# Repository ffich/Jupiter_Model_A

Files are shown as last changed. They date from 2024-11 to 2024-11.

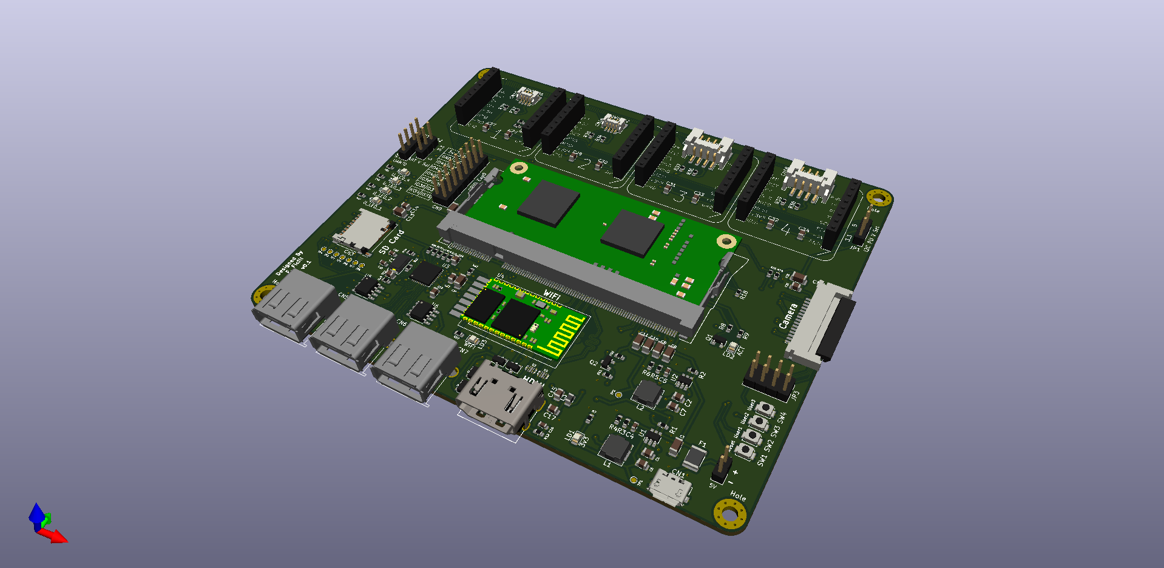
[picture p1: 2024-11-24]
10_HwProject/Jupiter_ModelA/50_3D/Jupiter_3D.png

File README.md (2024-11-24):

# Jupiter System
The Jupiter System is a system developed to leverage SW capabilities of Raspberry PI Compute Modules, by designing a system with an high level of HW configurability and scalability. This allows to use the power of the existing SW ecosystem in conjunction with a modular and scalable HW system, so that the user can take benefits from both of them. This HW configurability and expandability is given by adopting built-in sockets for some common peripheral add-on’s standard. The selected standards are the Mikroelektronika MikroBUS, the SeedStudio Grove and the Sparkfun QWIIC, which are widely used and open standards for HW expandability. The adherence to those standards allows the Jupiter System boards to be able to connect to the various expansion and breakout boards currently available on the market. These boards contain various types of sensor, actuators and interfaces, allowing for a very high level of HW scalability and modularity.

In this perspective the Jupiter System acts like a bridge between the Raspberry Pi SW and the HW world, allowing to take benefit from both the ecosystems.

Examples of application fields of Jupiter System are:
- Home automation System,
- IoT applications,
- Connectivity Applications,
- Monitoring and control Systems,
- Remote Control,
- Industrial Process control,
- Robotics applications,
- Test benches,
- Etc…

Concpet_Rpi

[youtube.com/watch?v=70Tqia20eaI](https://www.youtube.com/watch?v=70Tqia20eaI)

# Jupiter Model A
The Jupiter Model A is the desktop-version Jupiter board. It allows the user to experiment with the full potential of the Jupiter System. It's compatible with Raspberry CM3 and CM3+ (as the Raspberry Pi fundation does, we also strongly recommend to use CM3+ for newer design) and, among other peripherals, the board has 4 MikroBUS, 2 Grove and 2 Qwiic sockets that allow to create countless of combinations with Click, Grove or Qwiic slave devices.

Jupiter_3D

# MikroE Click Boards
There are more that 1000 click boards currently available on the market, and so many applications can be realized exploiting the power of raspberry (on SW side) and the high availability and modularity of the click boards (on the HW side).
For more information on click boards, please refer to the Mikroe website: https://www.mikroe.com/click





# Board Description
The HW block diagram of the Jupiter Model A is depicted below. As is possible to see, the brain of the system is a Raspberry PI compute module 3 or 3+, connected to a broad list of peripherals. 



More in details, the board is populated with:
-	3x USB
-	1x WiFi
-	1x CSI Interface
-	1x DSI interface
-	1x Boot SD card Socket
-	1x Serial Port
-	Up to 16 GPIO
-	4x User LEDs
-	2x User Buttons

Additionally the board contains 4 MikroBUS Sockets that allow to interface with MikroBUS compatible devices, like the click boards, 2 Groove and 2 QWIIC connectors.

HW Details

# Examples of combination with Click Boards

Model_A_1

Model_A_2

Model_A_3

Model_A_4

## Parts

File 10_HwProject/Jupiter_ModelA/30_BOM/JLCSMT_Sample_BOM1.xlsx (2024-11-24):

Comment | Designator | Footprint | LCSC Part #（optional）
100uF | C1 | CASE-B_3528 | C16133
100nF | C2, C9, C10 | 0603_C | C14663
10uF | C3-5 | 1206_C | C13585
15KΩ | R5, R6 | 0603_R | C22809

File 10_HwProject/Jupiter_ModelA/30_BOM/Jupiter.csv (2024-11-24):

Reference | Quantity | Value | Footprint | Description | Manf#
C1 C6 C2 C7 C15 | 5 | 22uF | Capacitor_SMD:C_0805_2012Metric | 0805_C
C12 C13 | 2 | 4.7uF | Capacitor_SMD:C_1206_3216Metric | 1206_C
C14 C22 C21 C23 C26 C27 C29 C31 C33 C28 C30 C32 C34 | 13 | 100nF | Capacitor_SMD:C_0805_2012Metric | 0805_C
C16 | 1 | 1nF | Capacitor_SMD:C_0603_1608Metric | 0603_C
C17 | 1 | 1nF | Capacitor_SMD:C_0805_2012Metric | 0805_C
C19 | 1 | 100n | Capacitor_SMD:C_0805_2012Metric | 0805_C
C20 C18 | 2 | 18pF | Capacitor_SMD:C_0603_1608Metric | 0603_C
C24 | 1 | 100uF | Capacitor_SMD:C_1206_3216Metric | 1206_C
C25 | 1 | 10uF | Capacitor_SMD:C_1206_3216Metric | 1206_C
C3 C8 C9 C10 C11 | 5 | 47uF | Capacitor_SMD:C_1206_3216Metric | 1206_C
C5 C4 | 2 | 22pF | Capacitor_SMD:C_0603_1608Metric | 0603_C
CN1 | 1 | USB_B_Micro | Connector_USB:USB_Micro-B_Molex_47346-0001 | USB MicroB Connector | Molex_47346
CN10 | 1 | 1 | mikroBUS:MIKROBUS_HOST_CONN | Mikrobus Socket - 2x PinHeader_2.54mm 1x08 female
CN11 | 1 | 2 | mikroBUS:MIKROBUS_HOST_CONN | Mikrobus Socket - 2x PinHeader_2.54mm 1x08 female
CN12 | 1 | UART0 | Connector_PinHeader_2.54mm:PinHeader_1x04_P2.54mm_Vertical | PinHeader_2.54mm 1x04 male
CN13 | 1 | 3 | mikroBUS:MIKROBUS_HOST_CONN | Mikrobus Socket - 2x PinHeader_2.54mm 1x08 female
CN14 | 1 | 4 | mikroBUS:MIKROBUS_HOST_CONN | Mikrobus Socket - 2x PinHeader_2.54mm 1x08 female
CN15 | 1 | QWIIC#1 | Connector_JST:JST_SH_SM04B-SRSS-TB_1x04-1MP_P1.00mm_Horizontal | JST_SH_SM04B-SRSS-TB_1x04-1MP_P1.00mm_Horizontal
CN16 | 1 | QWIIC#2 | Connector_JST:JST_SH_SM04B-SRSS-TB_1x04-1MP_P1.00mm_Horizontal | JST_SH_SM04B-SRSS-TB_1x04-1MP_P1.00mm_Horizontal
CN17 | 1 | GROVE#1 | Connector_JST:JST_PH_S4B-PH-SM4-TB_1x04-1MP_P2.00mm_Horizontal | JST_PH_S4B-PH-SM4-TB_1x04-1MP_P2.00mm_Horizontal
CN18 | 1 | GROVE#2 | Connector_JST:JST_PH_S4B-PH-SM4-TB_1x04-1MP_P2.00mm_Horizontal | JST_PH_S4B-PH-SM4-TB_1x04-1MP_P2.00mm_Horizontal
CN2 | 1 | 5V | Connector_PinHeader_2.54mm:PinHeader_1x02_P2.54mm_Vertical | PinHeader_1x02_P2.54mm_Vertical
CN3 | 1 | MicroSD | Connector_Card:microSD_HC_Hirose_DM3D-SF | MicroSD Connector | Hirose_DM3D-SF
CN4 | 1 | HDMI | FF_Connectors:HDMI_TypeA | HDMI Type A Connector
CN5 | 1 | USB_H2 | Connector_USB:USB_A_Stewart_SS-52100-001_Horizontal | USB Type A Connector | Stewart_SS-52100-001_Horizontal
CN6 | 1 | USB_H3 | Connector_USB:USB_A_Stewart_SS-52100-001_Horizontal | USB Type A Connector | Stewart_SS-52100-001_Horizontal
CN7 | 1 | USB_H4 | Connector_USB:USB_A_Stewart_SS-52100-001_Horizontal | USB Type A Connector | Stewart_SS-52100-001_Horizontal
CN8 | 1 | FPC15 | Connector_FFC-FPC:TE_1-84952-5_1x15-1MP_P1.0mm_Horizontal | FPC 15 Connector | TE_1-84952-5_1x15-1MP_P1.0mm_Horizontal
CN9 | 1 | GPIO Exp0 | Connector_PinHeader_2.54mm:PinHeader_2x08_P2.54mm_Vertical | PinHeader_2.54mm 2x08 male
D1 D2 D4 D6 | 4 | BAV99 | Package_TO_SOT_SMD:SOT-23 | SOT-23
D3 D5 | 2 | RCLAMP0524P | FF_Diodes:RCLAMP0524P | SLP2510P8-8
F1 | 1 | MSMF200 | Fuse:Fuse_1812_4532Metric | SMD 1812
JP1 | 1 | I2C PU V Sel | Connector_PinHeader_2.54mm:PinHeader_1x03_P2.54mm_Vertical | PinHeader_1x03 male
JP2 | 1 | UART V Sel | Connector_PinHeader_2.54mm:PinHeader_1x03_P2.54mm_Vertical | PinHeader_1x03 male
JP3 | 1 | Cam Jpr | Connector_PinHeader_2.54mm:PinHeader_2x04_P2.54mm_Vertical | PinHeader_2x04 male
L1 L2 | 2 | 2.2uH 3A | Inductor_SMD:L_Sunlord_MWSA0518_5.4x5.2mm | L_Sunlord_MWSA0518_5.4x5.2mm
L3 | 1 | Bead | Inductor_SMD:L_0805_2012Metric | 0805_L
LD1 | 1 | 3v3 | LED_SMD:LED_0805_2012Metric | LED_0805
LD2 | 1 | ACT | LED_SMD:LED_0805_2012Metric | LED_0805
LD3 | 1 | WiFi | LED_SMD:LED_0805_2012Metric | LED_0805
LD4 | 1 | U_LED_1 | LED_SMD:LED_0805_2012Metric | LED_0805
LD5 | 1 | U_LED_2 | LED_SMD:LED_0805_2012Metric | LED_0805
LD6 | 1 | U_LED_3 | LED_SMD:LED_0805_2012Metric | LED_0805
LD7 | 1 | U_LED_4 | LED_SMD:LED_0805_2012Metric | LED_0805
MD1 | 1 | RPi Compute Module | RPi_CM:Conn_TE-DDR2-SODIMM-0.6-200P-doublesided | SODIMM 200 | TE-DDR2-SODIMM-0.6-200P-doublesided
Q1 Q2 | 2 | S8050 | Package_TO_SOT_SMD:SOT-23 | S8050 SOT-23
R1 R2 R8 | 3 | 100k | Resistor_SMD:R_0603_1608Metric | 0603_R
R11 R10 R21 R17 R20 R16 R15 R14 | 8 | 10k | Resistor_SMD:R_0603_1608Metric | 0603_R
R12 | 1 | 100 | Resistor_SMD:R_0603_1608Metric | 0603_R
R13 | 1 | 1M | Resistor_SMD:R_0603_1608Metric | 0603_R
R18 | 1 | 1k | Resistor_SMD:R_0603_1608Metric | 0603_R
R19 | 1 | 12k | Resistor_SMD:R_0603_1608Metric | 0603_R
R23 | 1 | 4.7k | Resistor_SMD:R_0603_1608Metric | 0603_R
R24 R25 R27 R26 R33 R32 R35 R34 R37 R36 R39 R38 | 12 | 2.2k | Resistor_SMD:R_0603_1608Metric | 0603_R
R3 R6 | 2 | 150k | Resistor_SMD:R_0603_1608Metric | 0603_R
R4 | 1 | 33k | Resistor_SMD:R_0603_1608Metric | 0603_R
R5 | 1 | 300k | Resistor_SMD:R_0603_1608Metric | 0603_R
R7 R28 R29 R30 R31 | 5 | 220 | Resistor_SMD:R_0603_1608Metric | 0603_R
R9 R22 | 2 | 330 | Resistor_SMD:R_0603_1608Metric | 0603_R
SW1 | 1 | Reset | Button_Switch_SMD:SW_SPST_B3U-1000P | Omron B3U-1000P
SW2 | 1 | User1 | Button_Switch_SMD:SW_SPST_B3U-1000P | Omron B3U-1000P
SW3 | 1 | User2 | Button_Switch_SMD:SW_SPST_B3U-1000P | Omron B3U-1000P
SW4 | 1 | User3 | Button_Switch_SMD:SW_SPST_B3U-1000P | Omron B3U-1000P
TP1 TP2 TP5 TP9 TP8 TP7 TP6 TP4 TP3 | 9 |  | TestPoint:TestPoint_Pad_D1.0mm
U1 U2 | 2 | AP3402 | Package_TO_SOT_SMD:TSOT-23-6 | TSOT-23-6
U3 | 1 | USB2514B_Bi | Package_DFN_QFN:QFN-36-1EP_6x6mm_P0.5mm_EP3.7x3.7mm | QFN-36
U4 | 1 | GWF_3M08 | FF_Modules:GWF_3M08_WifiModule | Kit Wifi GWF-3M08
U5 U6 | 2 | MIC2026-1BM | Package_SO:SOIC-8_3.9x4.9mm_P1.27mm | SOIC-8
Y1 | 1 | 24 MHz | Crystal:Crystal_SMD_5032-2Pin_5.0x3.2mm | SMD_5032

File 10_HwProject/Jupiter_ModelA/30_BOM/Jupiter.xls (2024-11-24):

Comment | Designator | Footprint
22uF | C1 C6 C2 C7 C35 | 0805_C
4.7uF | C12 C13 | 1206_C
100nF | C14 C20 C19 C21 C26 C25 C27 C29 C31 C33 C28 C30 C32 C34 | 0805_C
1nF | C15 | 0603_C
100n | C17 | 0805_C
18pF | C18 C16 | 0603_C
100uF | C22 | 1206_C
10uF | C24 C23 | 1206_C
47uF | C3 C8 C9 C10 C11 | 1206_C
1nF | C36 | 0805_C
22pF | C5 C4 | 0603_C
USB_B_Micro | CN1 | USB MicroB Connector
GPIO Exp1 | CN10 | PinHeader_2.54mm 2x08 male
UART0 | CN11 | PinHeader_2.54mm 1x04 male
1 | CN12 | Mikrobus Socket - 2x PinHeader_2.54mm 1x08 female
2 | CN13 | Mikrobus Socket - 2x PinHeader_2.54mm 1x08 female
3 | CN14 | Mikrobus Socket - 2x PinHeader_2.54mm 1x08 female
4 | CN15 | Mikrobus Socket - 2x PinHeader_2.54mm 1x08 female
Pwr | CN16
5V | CN17
MicroSD | CN2 | MicroSD Connector
HDMI | CN3 | HDMI Type A Connector
USB_H2 | CN4 | USB Type A Connector
USB_H3 | CN5 | USB Type A Connector
USB_H4 | CN6 | USB Type A Connector
FPC15 | CN8 CN7 | FPC 15 Connector
GPIO Exp0 | CN9 | PinHeader_2.54mm 2x08 male
BAV99 | D1 D2 D4 D6 | SOT-23
RCLAMP0524P | D3 D5 | SLP2510P8-8
MSMF200 | F1 | SMD 1812
Fuse Bp | JP1 | PinHeader_1x02 male
I2C PU V Sel | JP2 | PinHeader_1x03 male
UART V Sel | JP3 | PinHeader_1x03 male
2.2uH 3A | L1 L2 | L_Sunlord_MWSA0518_5.4x5.2mm
Bead | L3 | 0805_L
5v | LD1 | LED_0805
3v3 | LD2 | LED_0805
1V8 | LD3 | LED_0805
ACT | LD4 | LED_0805
WiFi | LD5 | LED_0805
U_LED_1 | LD6 | LED_0805
U_LED_2 | LD7 | LED_0805
U_LED_3 | LD8 | LED_0805
U_LED_4 | LD9 | LED_0805
RPi Compute Module | MD1 | SODIMM 200
S8050 | Q1 Q2 | S8050 SOT-23
100k | R1 R2 R10 | 0603_R
330 | R11 R24 | 0603_R
10k | R13 R12 R23 R19 R22 R18 R17 R16 | 0603_R
100 | R14 | 0603_R
1M | R15 | 0603_R
1k | R20 | 0603_R
12k | R21 | 0603_R
4.7k | R25 | 0603_R
2.2k | R26 R27 R29 R28 | 0603_R
150k | R3 R6 | 0603_R
33k | R4 | 0603_R
300k | R5 | 0603_R
220 | R7 R8 R9 R30 R31 R32 R33 | 0603_R
 | TP1 TP2 TP6 TP7 TP11 TP15 TP14 TP13 TP12 TP10 TP9
AP3402 | U1 U2 | TSOT-23-6
USB2514B_Bi | U3 | QFN-36
GWF_3M08 | U4
MIC2026-1BM | U5 U6 | SOIC-8
24 MHz | Y1 | SMD_5032

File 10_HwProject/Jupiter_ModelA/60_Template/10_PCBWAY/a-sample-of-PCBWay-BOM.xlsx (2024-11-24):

 |  |  | xxxx xxxx xxxxx xxPCS BOM (Sample Bill of Materials)
Item # | *Designator | *Qty | Manufacturer | *Mfg Part # | Description / Value | *Package/Footprint | Type | Your Instructions / Notes
1 | U1 | 1 | Linear | LTC3780EG#PBF | IC BUCK-BOOST CONV 24-SSOP | 24-SSOP | SMD
2 | U2,U4 | 2 | Fairchild | LM2904M | IC OPAMP DUAL -40-85 C 8-SOIC | 8-SOIC | DNS
3 | U3 | 1 | ON | LM317MBDTG | LM317M IC REG VOLT ADJ 500MA DPAK | DPAK | SMD
4 | U5 | 1 | Microchip | PIC16F690-I/SS | IC PIC MCU FLASH 4KX14 20SSOP | 20SSOP | SMD
5 | Q1 | 1 | Diodes Inc | GBJ10005-F | RECT BRIDGE GPP 50V 10A GBJ | GBJ | SMD
6 | R14,R18 | 2 | Panasonic | ERJ-6ENF4701V | RES 4.70K OHM 1/8W 1% 0805 SMD | 0805 | SMD
7 | R15 | 1 | Susumu | RL3720WT-R022-F | RES .022 OHM 1W 1% 0815 SMD | 0815 | SMD
8 | R16, R31 | 2 | Panasonic | ERJ-6ENF4702V | RES 47.0K OHM 1/8W 1% 0805 SMD | 0805 | SMD
9 | C5 | 1 | Murata | GRM21BR71C225KA12L | CAP CER 2.2UF 16V X7R 0805 | 0805 | SMD
10 | C7 | 1 | Murata | GRM21BR71C475KA73L | CAP CER 4.7UF 16V X7R 0805 | 0805 | DNS
11 | C8,C22 | 2 | Muruta | GRM21BR71C105KA01L | CAP CER 1.0UF 16V 10% X7R 0805 | 0805 | SMD
12 | CN6 | 1 | Molex | 538-53398-0671 | 1.25mm Connectors VERTICAL HDR SMT 6P | SMT 6P | SMD
13 | L1,L2 | 2 | Coiltronics | DR127-150-R | INDUCTOR SHIELD PWR 15UH SMD | SMD | SMD
14 | L3 | 1 | TDK | ACM1211-102-2PL-TL | CHOKE COMM MODE 1000 OHM 6A SM | SMD | SMD
15 | CN3,CN4 | 2 | Molex | 53047-0510 | CONN HEADER 5POS 1.25MM VERT TIN | 5POS | thru-hole
Need a quick and accurante quote? Need an efficient production? Please read SMT Ordering Necessary Files & Info in 1 minute. Thank you very much! (https://www.pcbway.com/smt_ordering_guide.html)
Click for Instructions on How to Create a BOM (https://www.pcbway.com/blog/PCB_Assembly/How_to_Build_a_BOM__Bill_Of_Materials_.html)

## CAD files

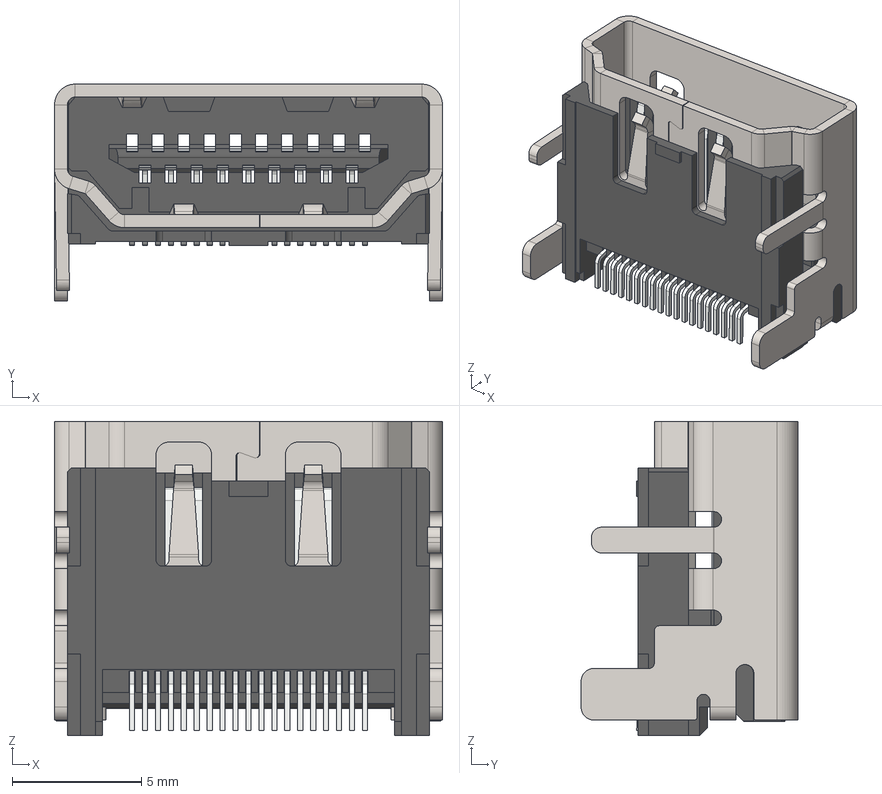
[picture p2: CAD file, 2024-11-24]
10_HwProject/Jupiter_ModelA/10_PCB/Jupiter/3d/molex_0471510001.STEP
15.0 x 8.38 x 12.1 mm

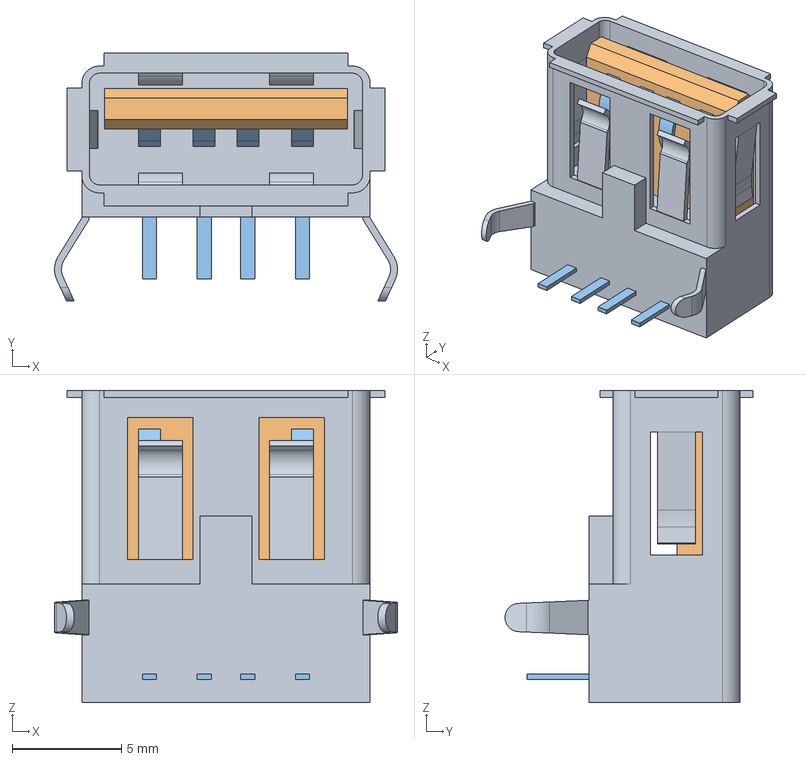
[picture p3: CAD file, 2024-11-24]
10_HwProject/Jupiter_ModelA/10_PCB/Jupiter/3d/USBR-A-S-F-O-TH.stp
15.7 x 11.3 x 14.3 mm
_USBR-A-S-TH_s
_USBR-A-S-TH_b
_USBR-A-S-TH_p

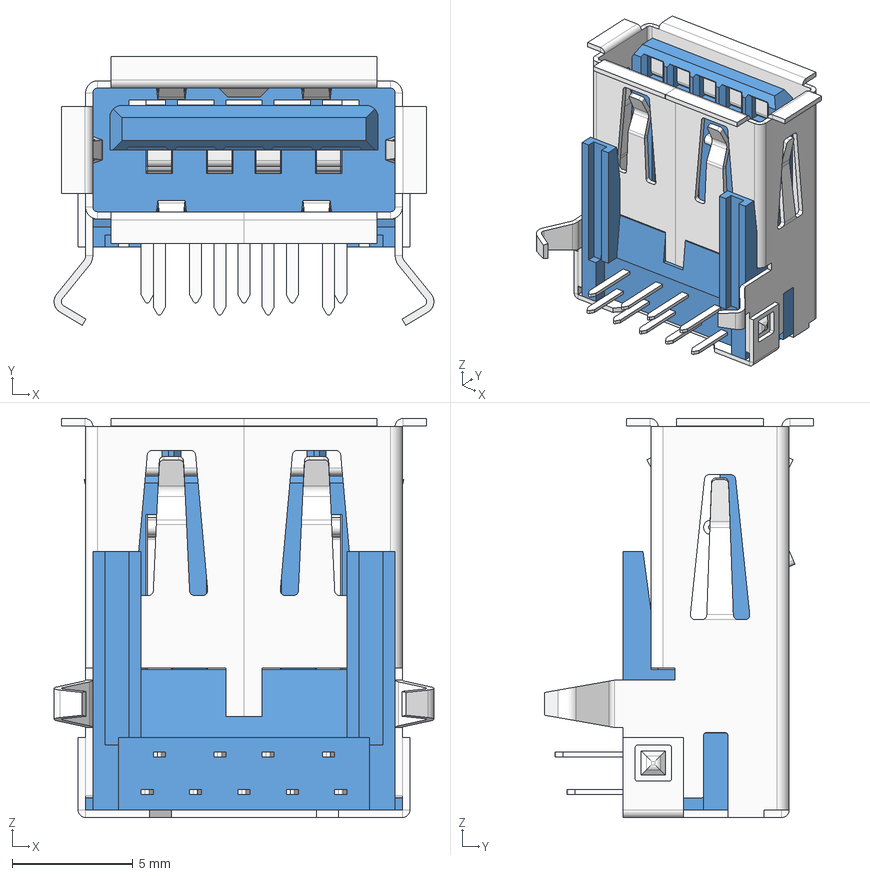
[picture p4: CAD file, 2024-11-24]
10_HwProject/Jupiter_ModelA/10_PCB/Jupiter/3d/USB 3.0 A Recepticle.stp
15.7 x 11.1 x 16.5 mm
USB 3.0 A Recepticle Shell
USB 3.0 A Recepticle Insert Fit
USB 3.0 A Recepticle Rear Insert Fit
USB 3.0 A Recepticle Lower Pin x 4
USB 3.0 A Recepticle Upper Pin x 5

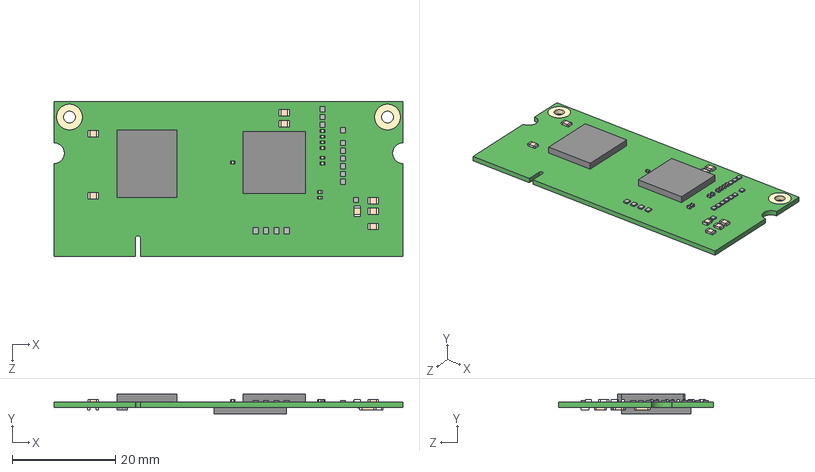
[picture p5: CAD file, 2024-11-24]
10_HwProject/Jupiter_ModelA/10_PCB/Jupiter/3d/RASPBERRYPI-CM3.STEP
67.6 x 3.80 x 30.0 mm

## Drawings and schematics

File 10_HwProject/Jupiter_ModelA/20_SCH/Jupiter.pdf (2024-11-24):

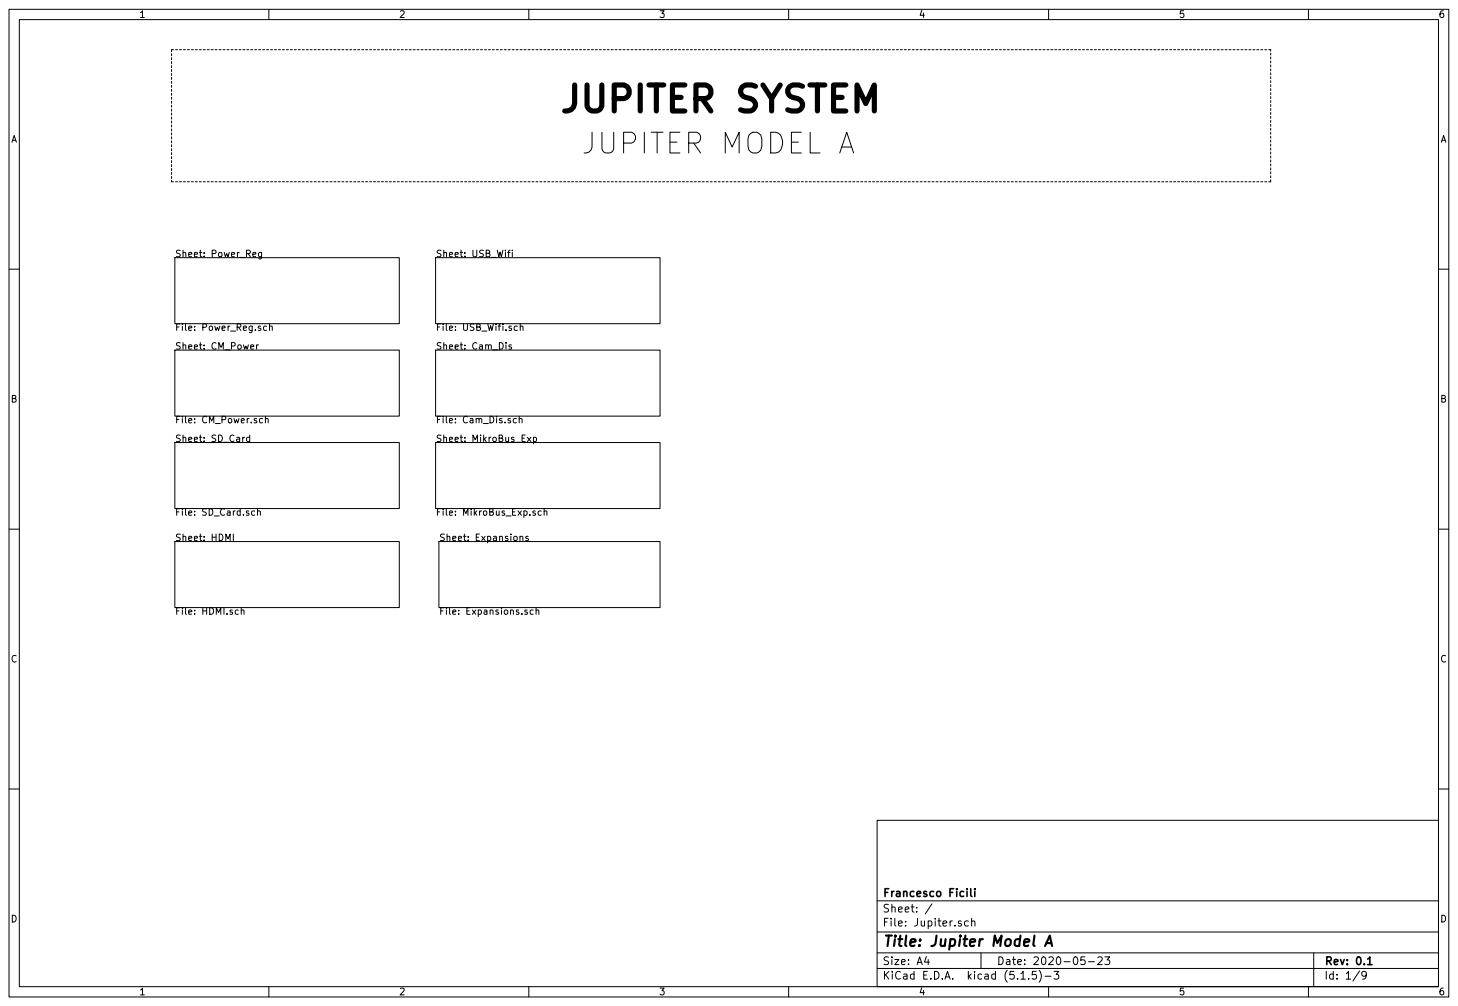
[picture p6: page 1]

File: Jupiter.sch Sheet: / Francesco Ficili

Id: 1/9 Title: Jupiter Model A

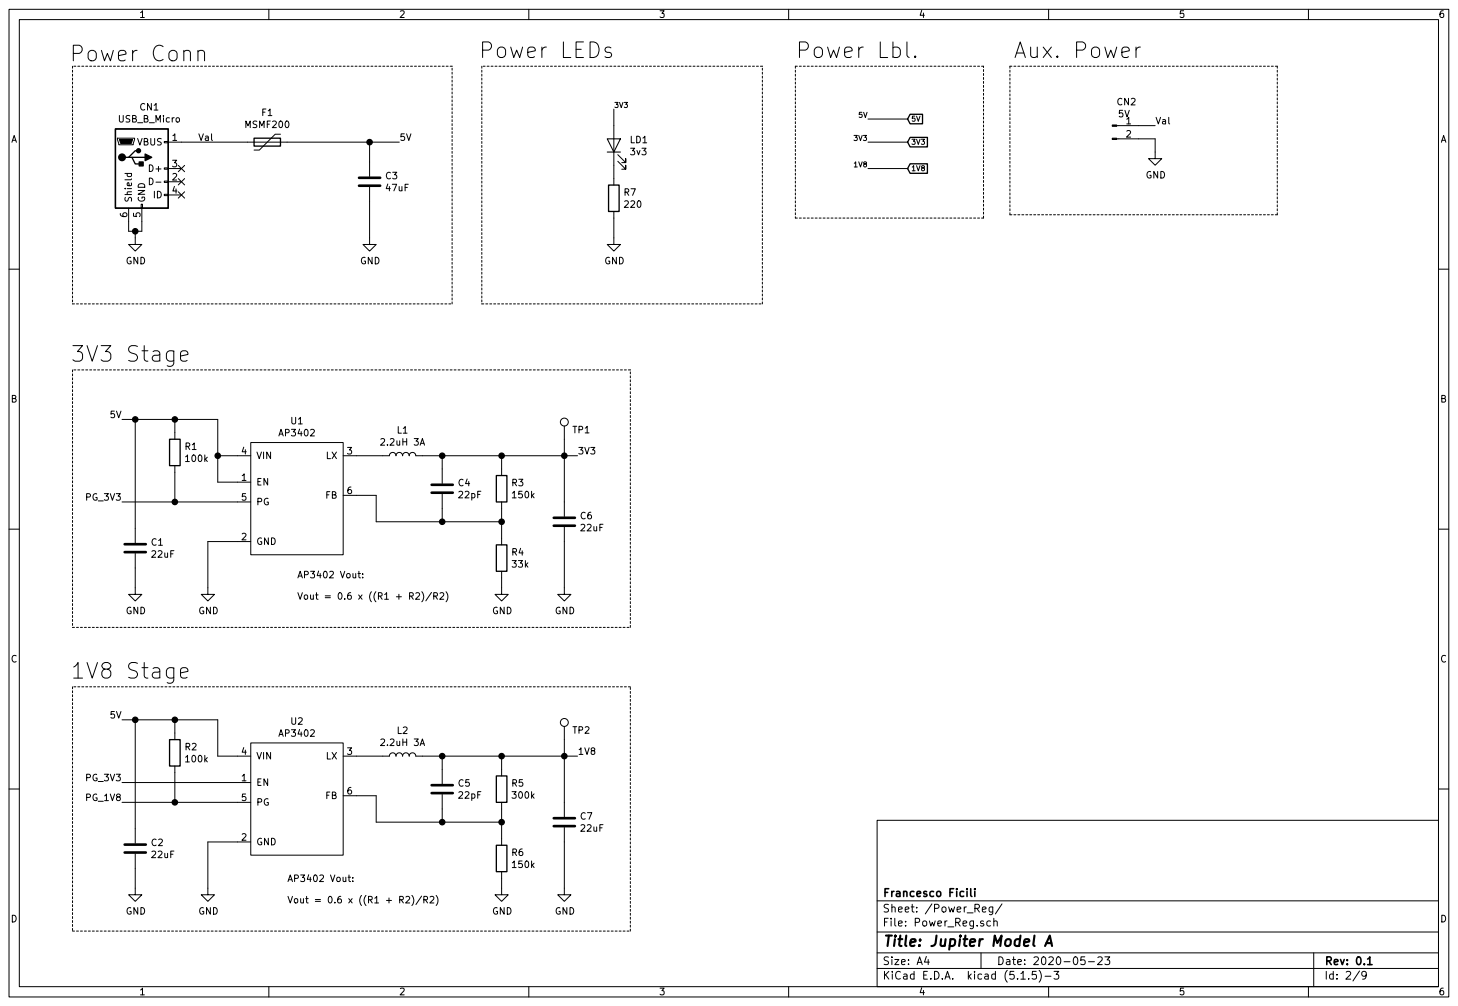
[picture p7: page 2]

3V3 Stage
AP3402 Vout: Vout = 0.6 x ((R1 + R2)/R2)

File: Power_Reg.sch
Id: 2/9 Title: Jupiter Model A

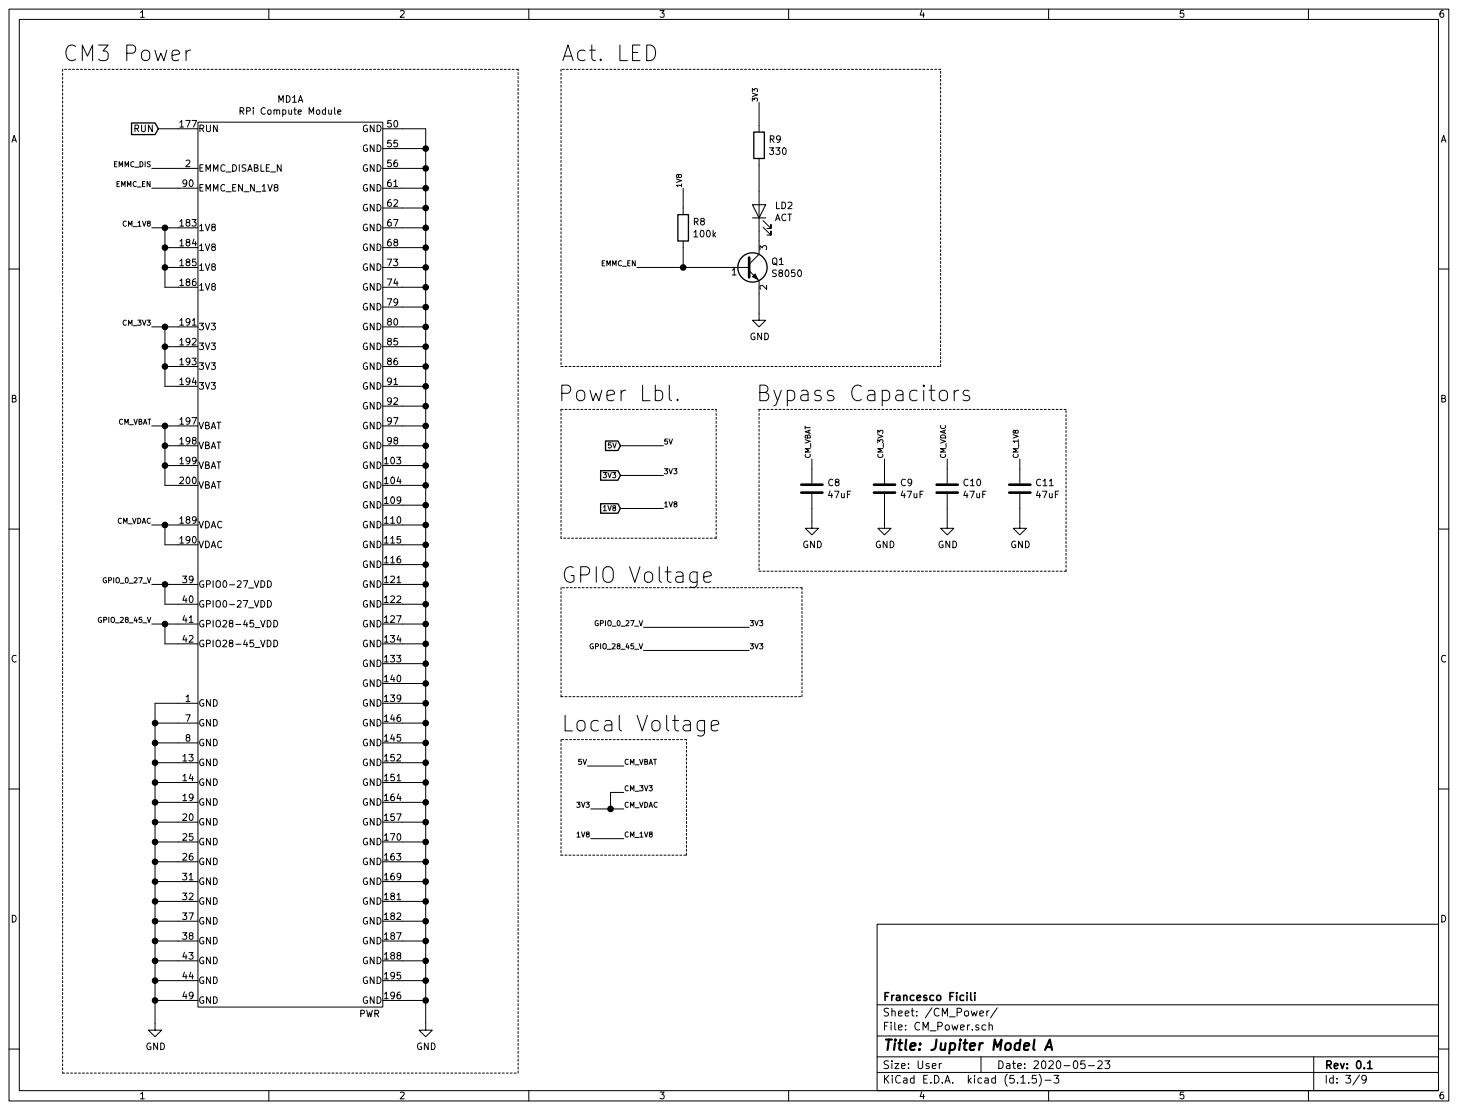
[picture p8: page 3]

File: CM_Power.sch
Id: 3/9 Title: Jupiter Model A

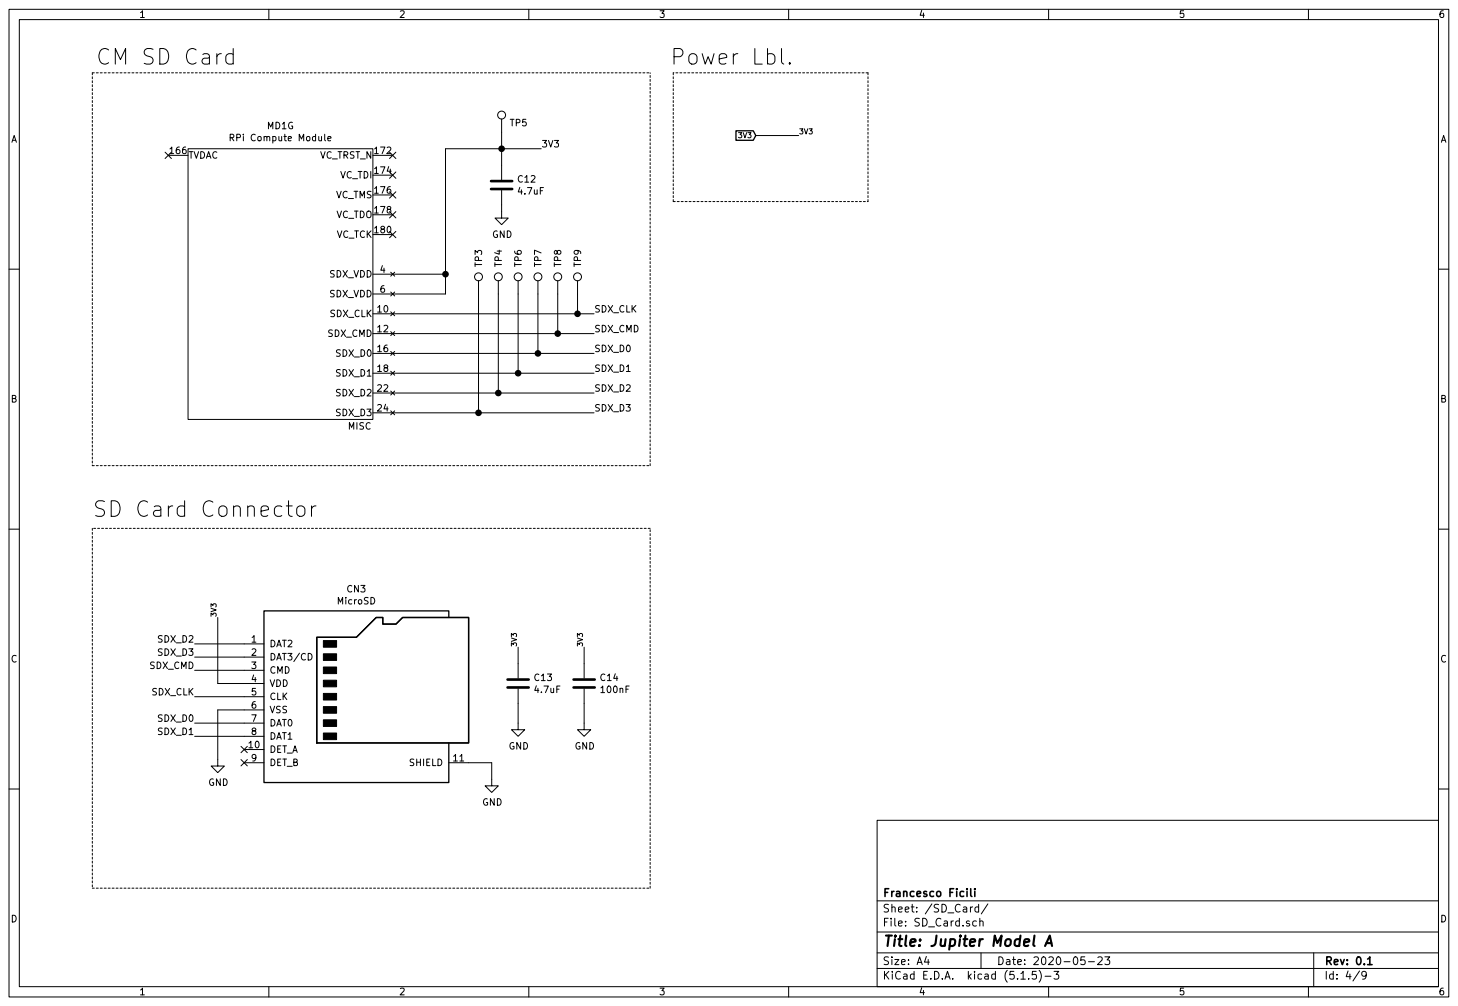
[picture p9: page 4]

File: SD_Card.sch
Id: 4/9 Title: Jupiter Model A

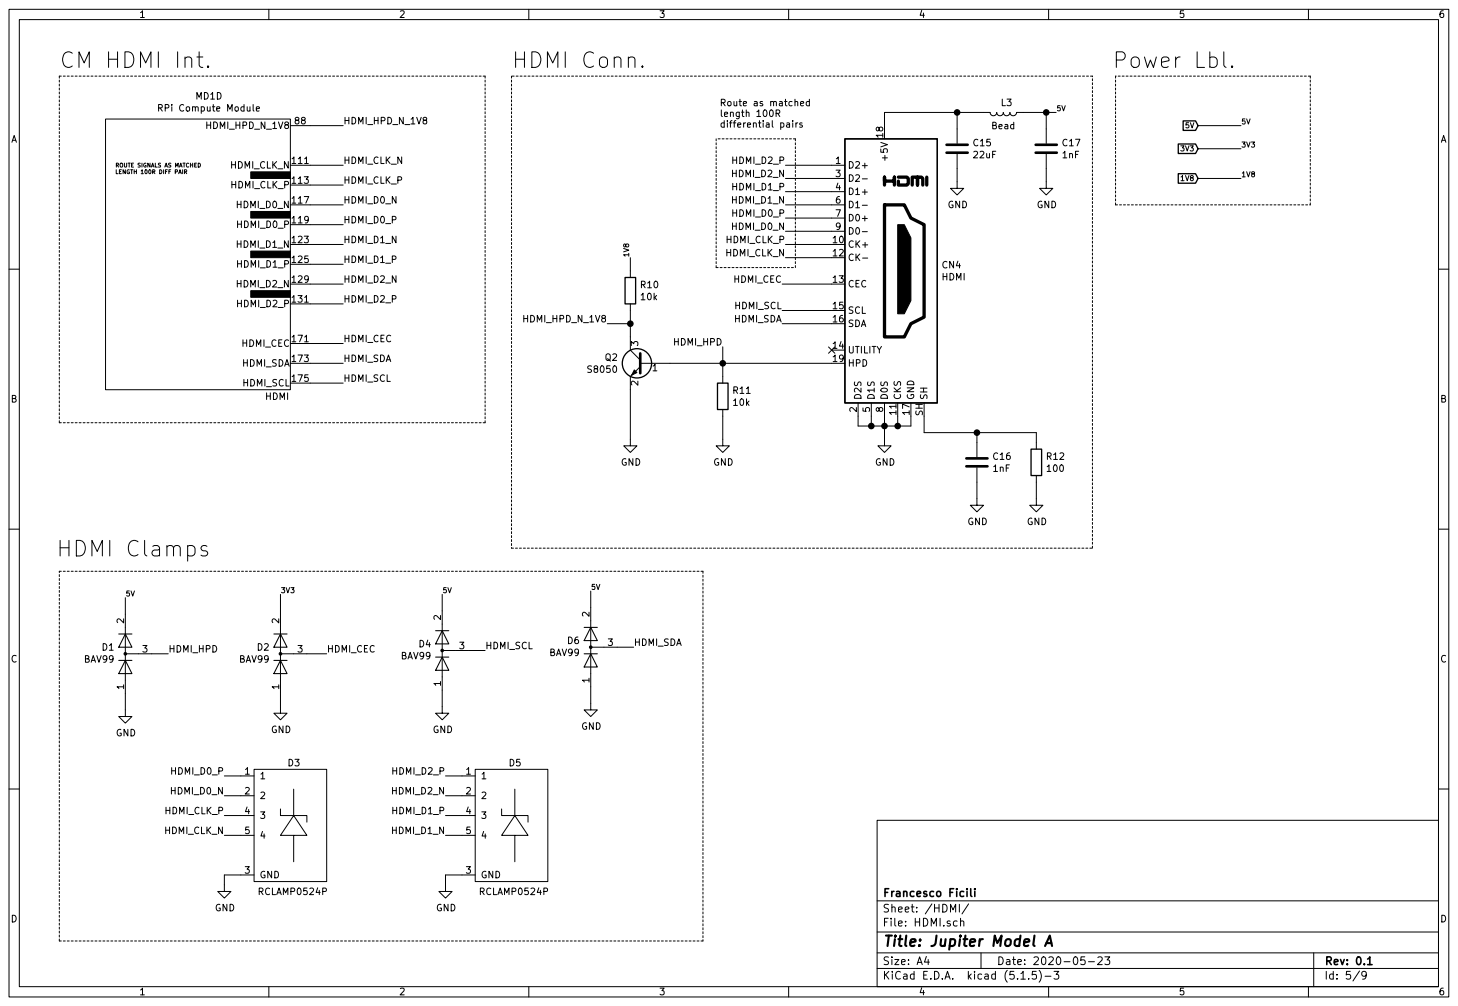
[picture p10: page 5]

Id: 5/9 Title: Jupiter Model A

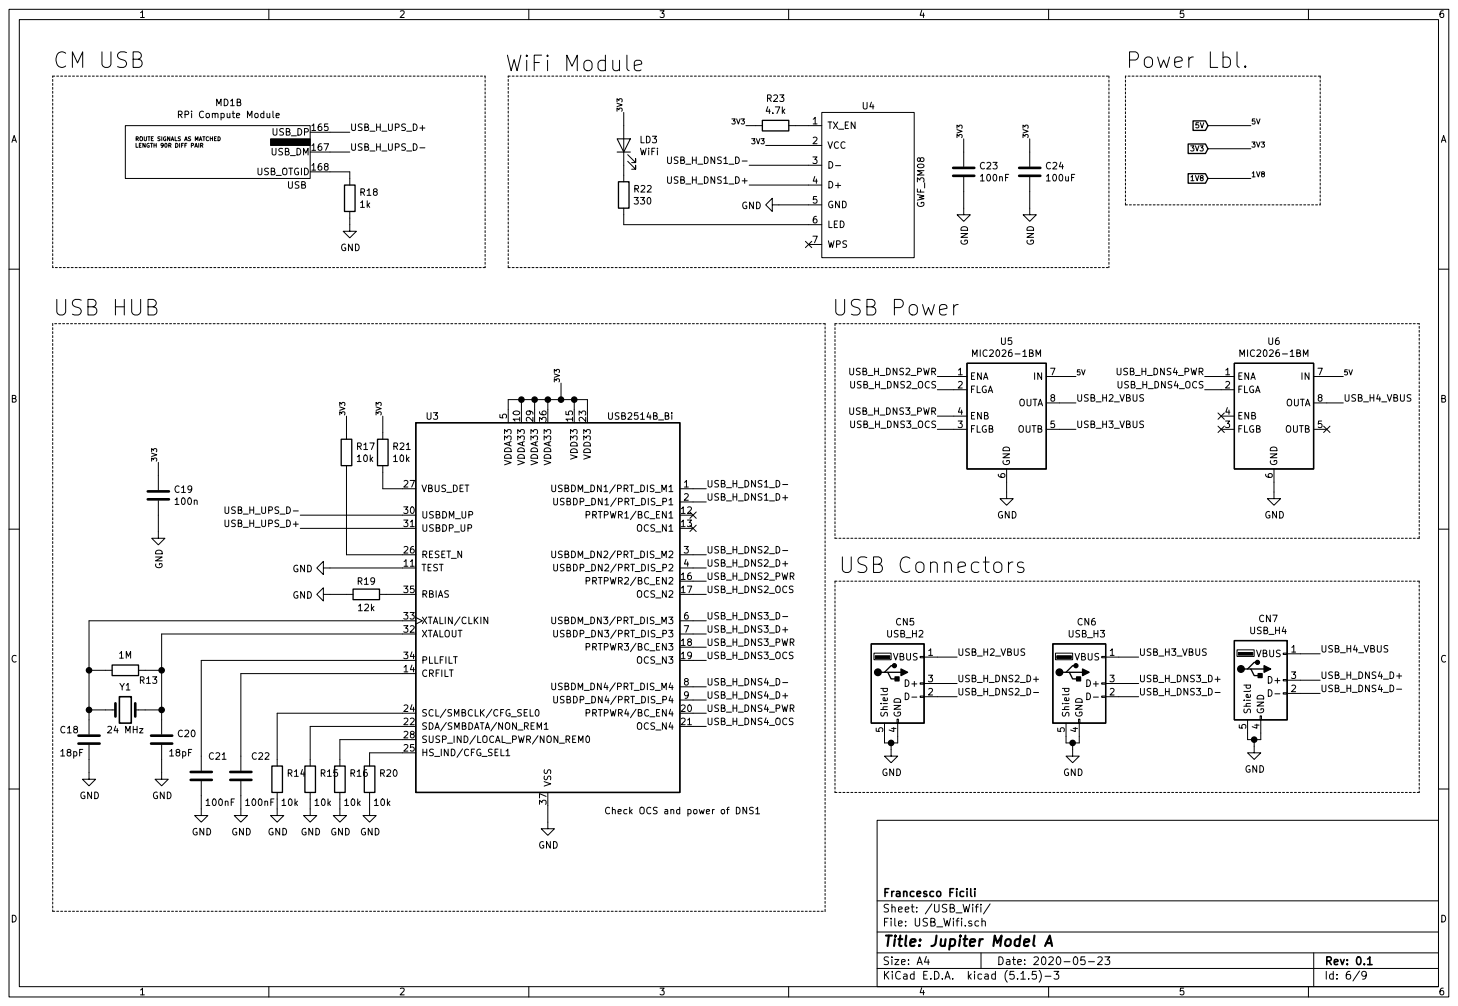
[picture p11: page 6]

5 CN6 USB_H3 GND GND GND GND GND

Check OCS and power of DNS1

File: USB_Wifi.sch
Id: 6/9 Title: Jupiter Model A

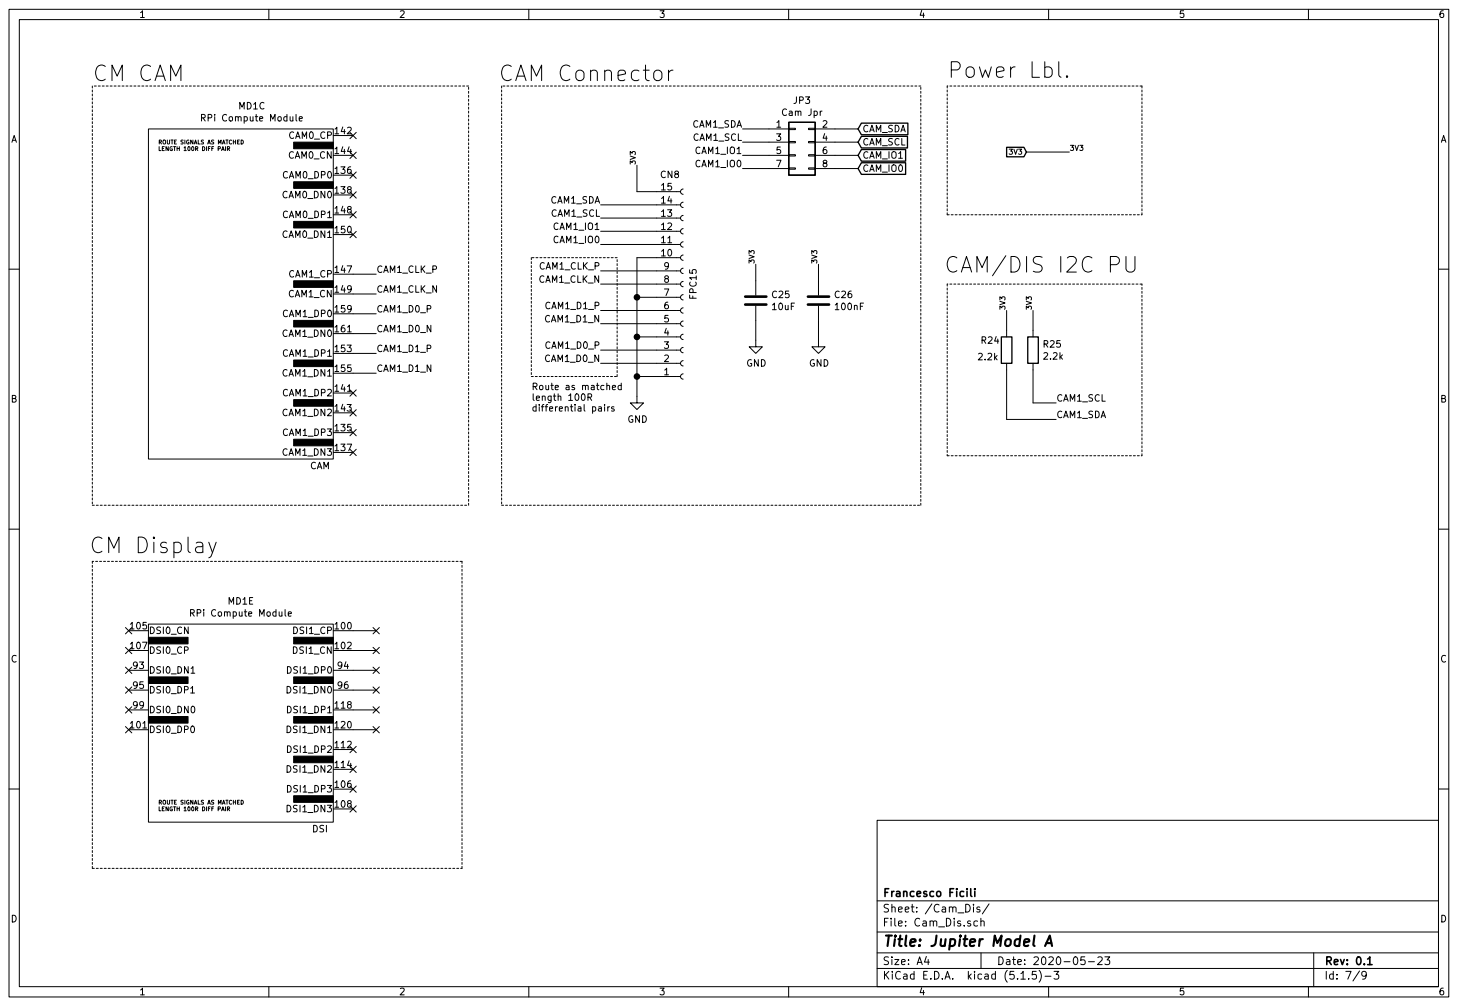
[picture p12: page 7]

Sheet: /Cam_Dis/ Francesco Ficili DSI LENGTH 100R DIFF PAIR

File: Cam_Dis.sch
Id: 7/9 Title: Jupiter Model A

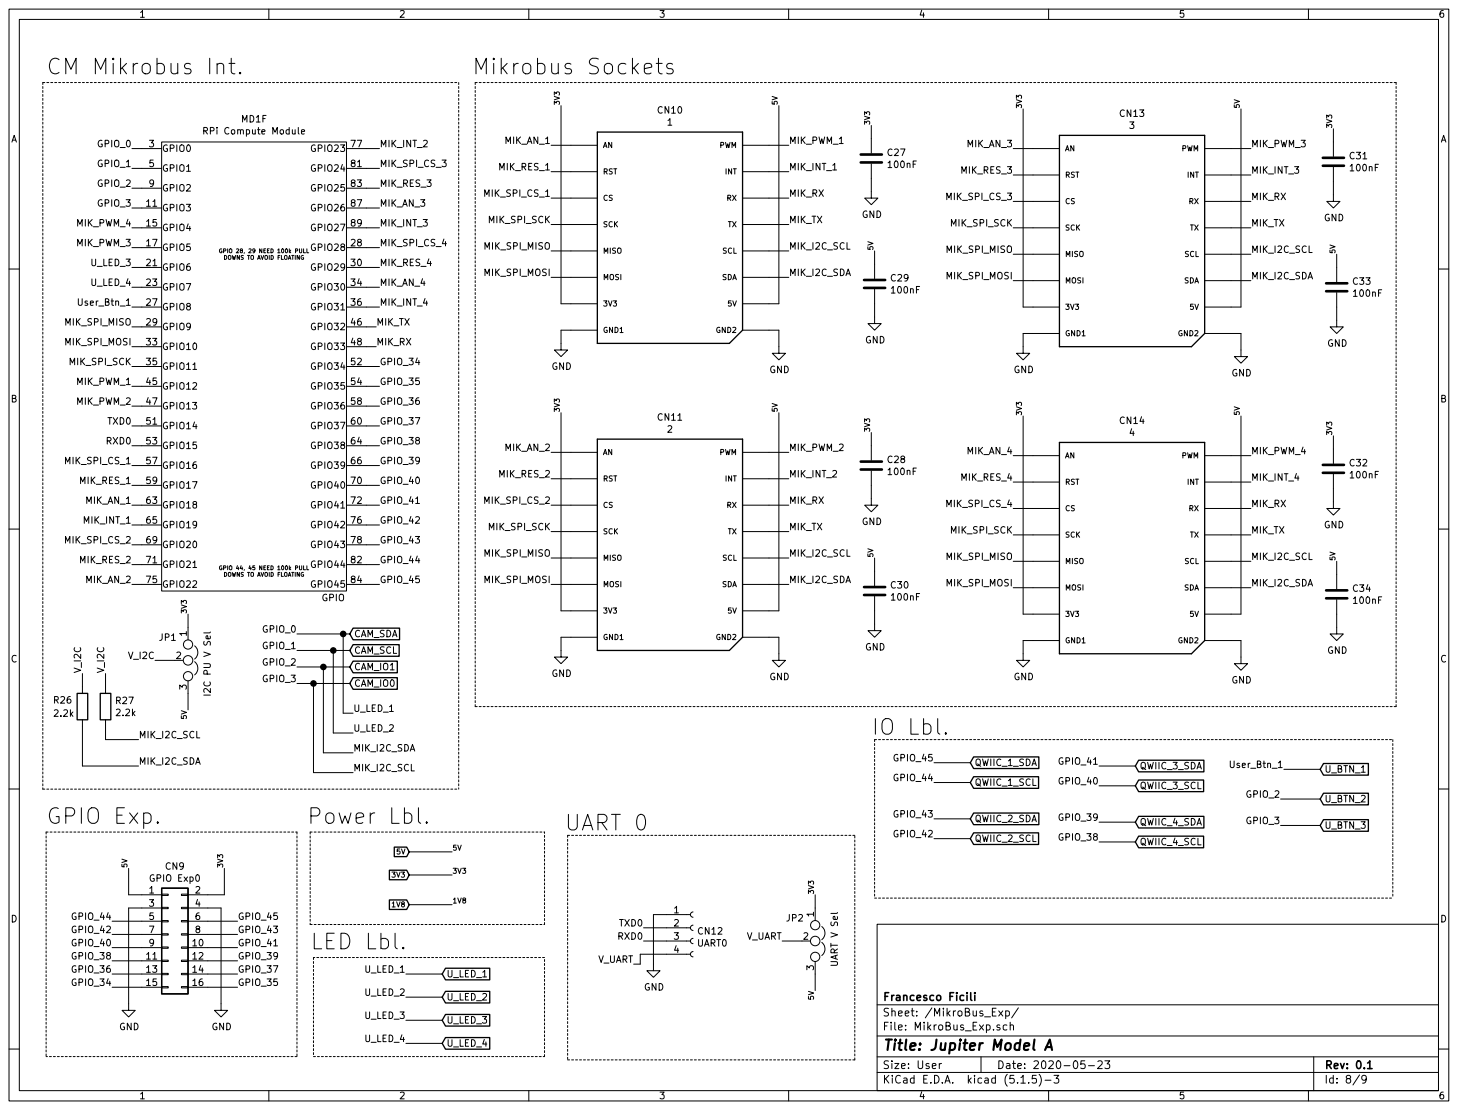
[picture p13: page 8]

DOWNS TO AVOID FLOATING

File: MikroBus_Exp.sch
Id: 8/9 Title: Jupiter Model A

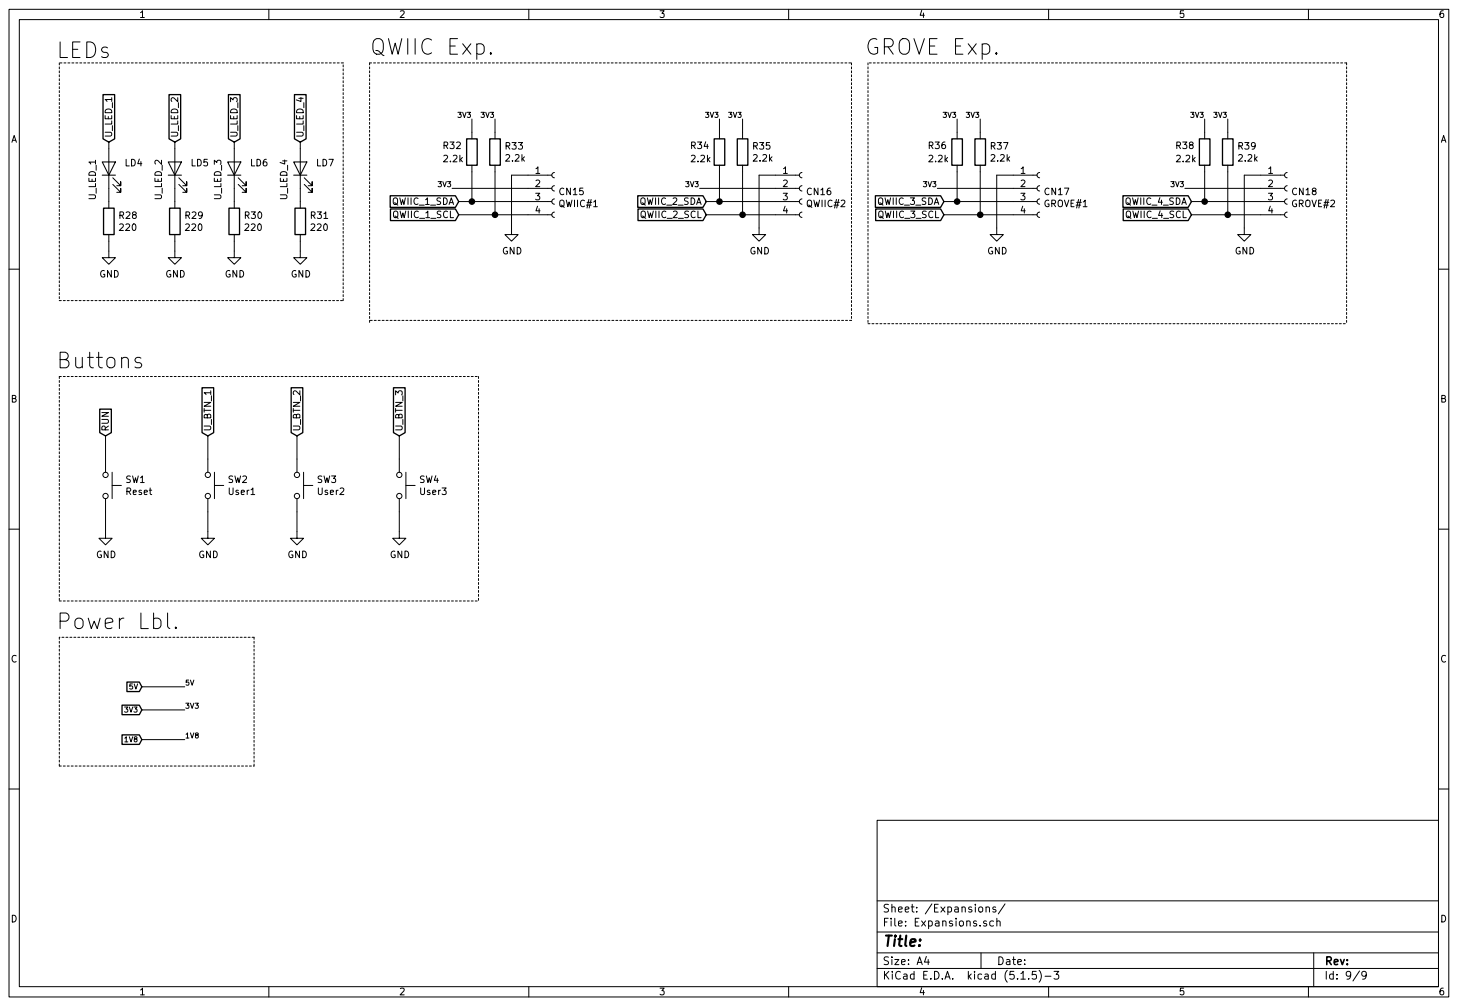
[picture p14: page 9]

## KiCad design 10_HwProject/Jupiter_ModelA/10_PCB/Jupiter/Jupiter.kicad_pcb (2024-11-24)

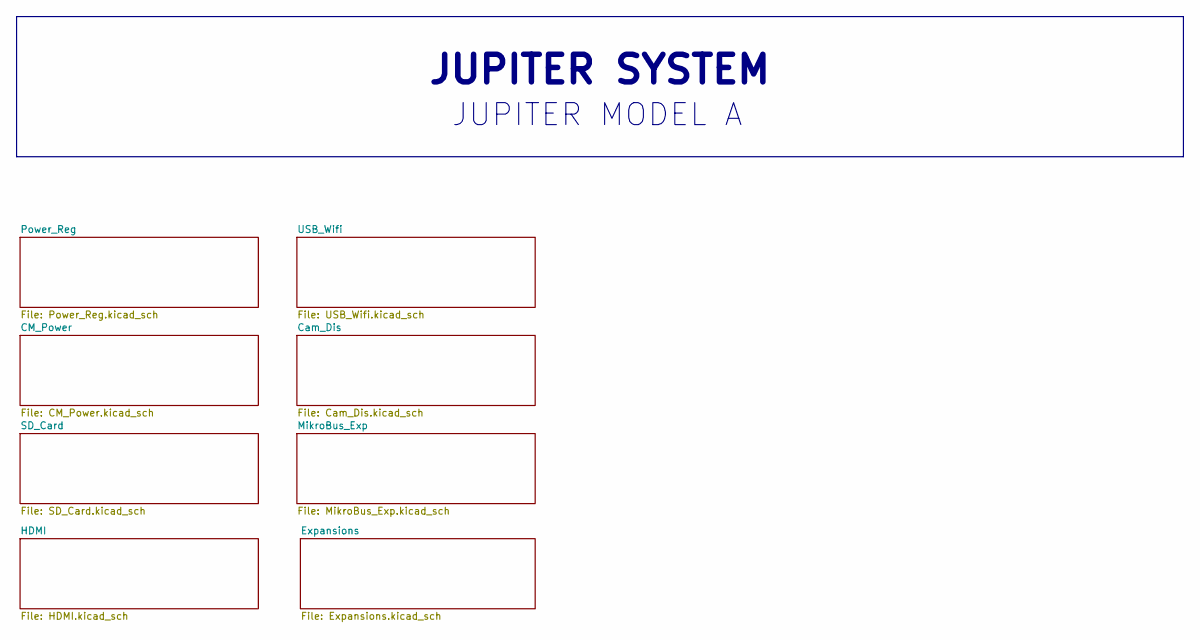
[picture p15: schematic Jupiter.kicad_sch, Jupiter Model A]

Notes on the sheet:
JUPITER SYSTEM
JUPITER MODEL A

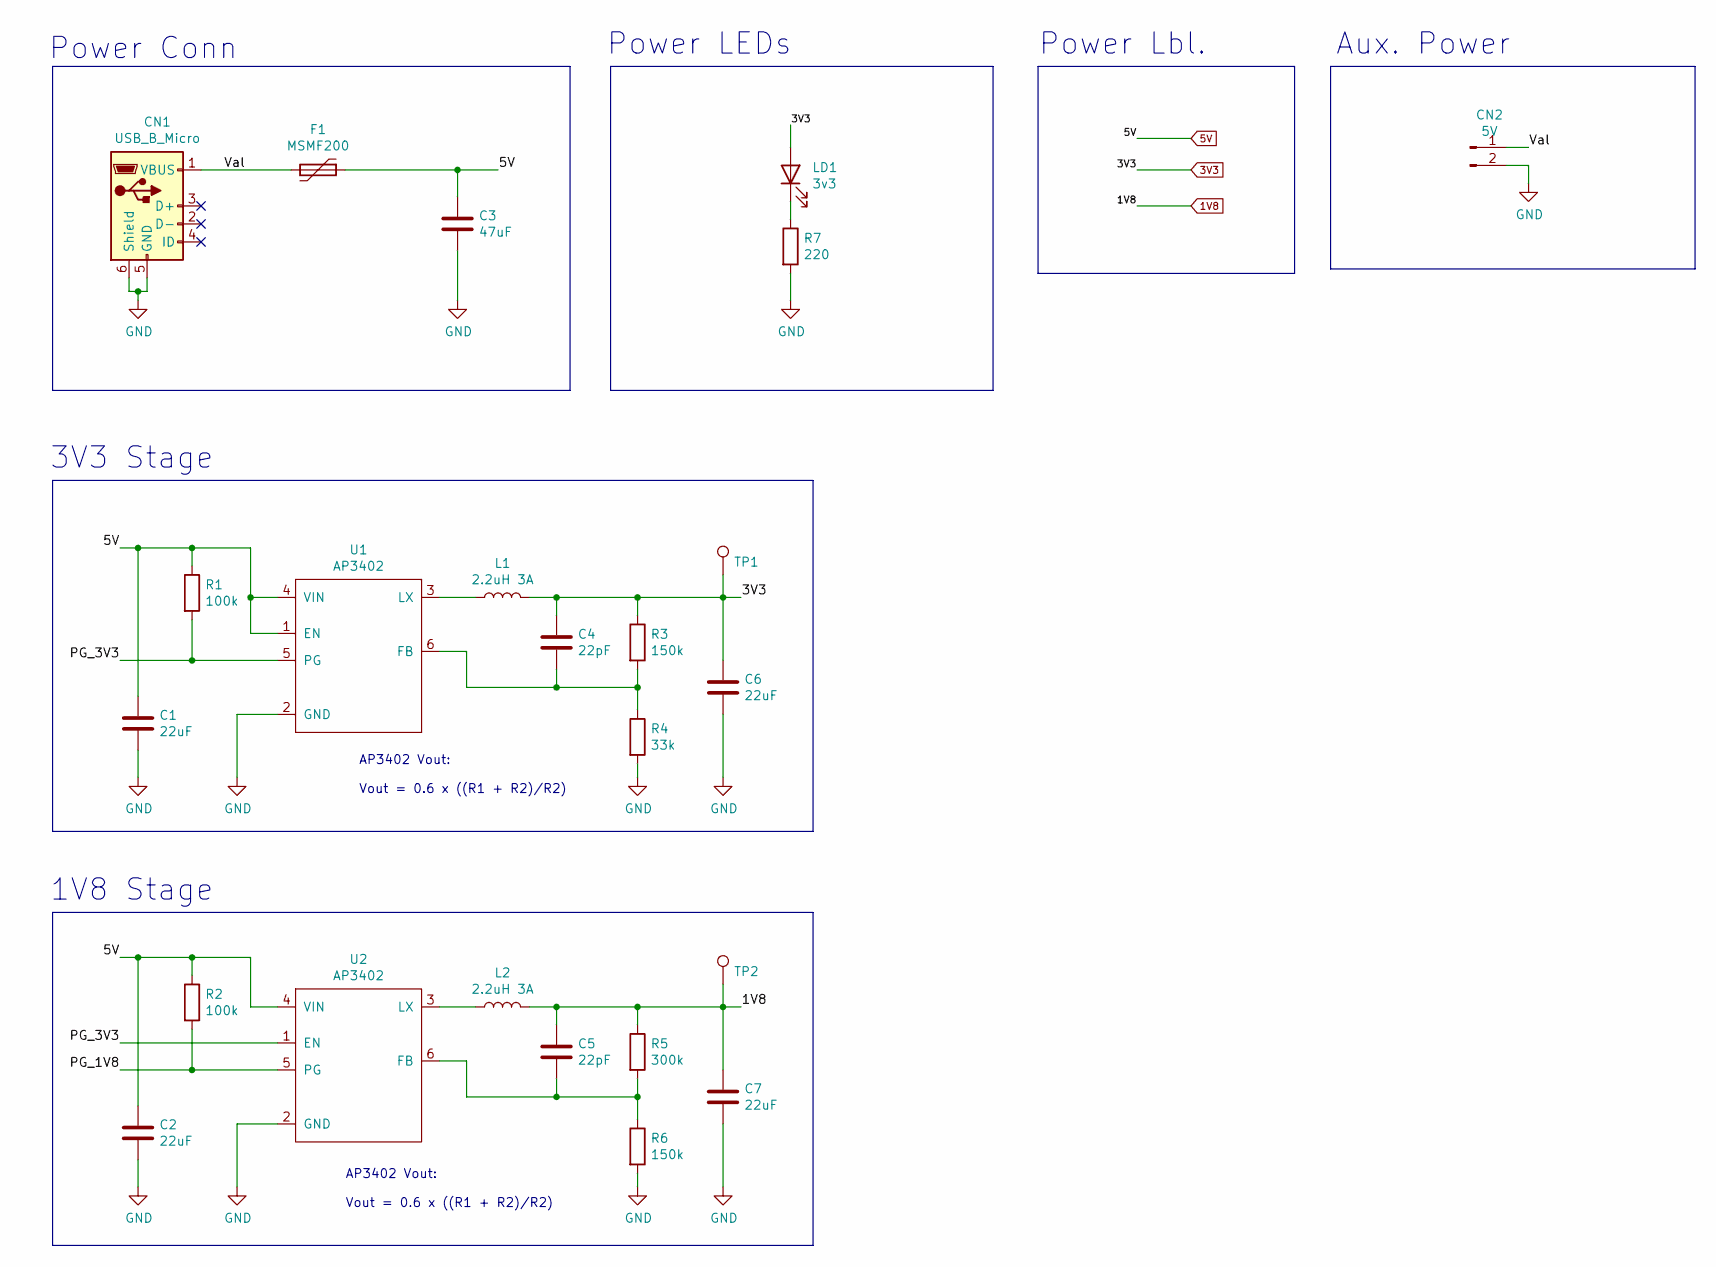
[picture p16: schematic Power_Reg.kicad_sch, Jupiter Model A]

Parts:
C1, C2, C6, C7: 22uF; C_0805_2012Metric
C3: 47uF; C_1206_3216Metric
C4, C5: 22pF; C_0603_1608Metric
CN1: USB_B_Micro; USB_Micro-B_Molex_47346-0001
CN2: 5V; PinHeader_1x02_P2.54mm_Vertical
F1: MSMF200; Fuse_1812_4532Metric
L1, L2: 2.2uH 3A; L_Sunlord_MWSA0518_5.4x5.2mm
LD1: 3v3; LED_0805_2012Metric
R1, R2: 100k; R_0603_1608Metric
R3, R6: 150k; R_0603_1608Metric
R4: 33k; R_0603_1608Metric
R5: 300k; R_0603_1608Metric
R7: 220; R_0603_1608Metric
TP1, TP2: TestPoint_Pad_D1.0mm
U1, U2: AP3402; TSOT-23-6

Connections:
1V8: C5.1, C7.1, L2.2, R5.1, TP2.1; also elsewhere on the board
3V3: C4.1, C6.1, L1.2, LD1.2 (A), R3.1, TP1.1; also elsewhere on the board
5V: C1.1, C2.1, C3.1, F1.1, R1.1, R2.1, U1.1 (EN), U1.4 (VIN), U2.4 (VIN); also elsewhere on the board
/Power_Reg/PG_1V8: R2.2, U2.5 (PG)
/Power_Reg/PG_3V3: R1.2, U1.5 (PG), U2.1 (EN)
/Power_Reg/Val: CN1.1 (VBUS), CN2.1, F1.2
GND: C1.2, C2.2, C3.2, C6.2, C7.2, CN1.5 (GND), CN1.6 (Shield), CN2.2, R4.2, R6.2, R7.2, U1.2 (GND), U2.2 (GND); also elsewhere on the board
unnamed: C4.2, R3.2, R4.1, U1.6 (FB)
unnamed: C5.2, R5.2, R6.1, U2.6 (FB)
unnamed: L1.1, U1.3 (LX)
unnamed: L2.1, U2.3 (LX)
unnamed: LD1.1 (K), R7.1

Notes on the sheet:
AP3402 Vout: Vout = 0.6 x ((R1 + R2)/R2)
Aux. Power
3V3 Stage
Power Lbl.
Power LEDs
Power Conn
1V8 Stage

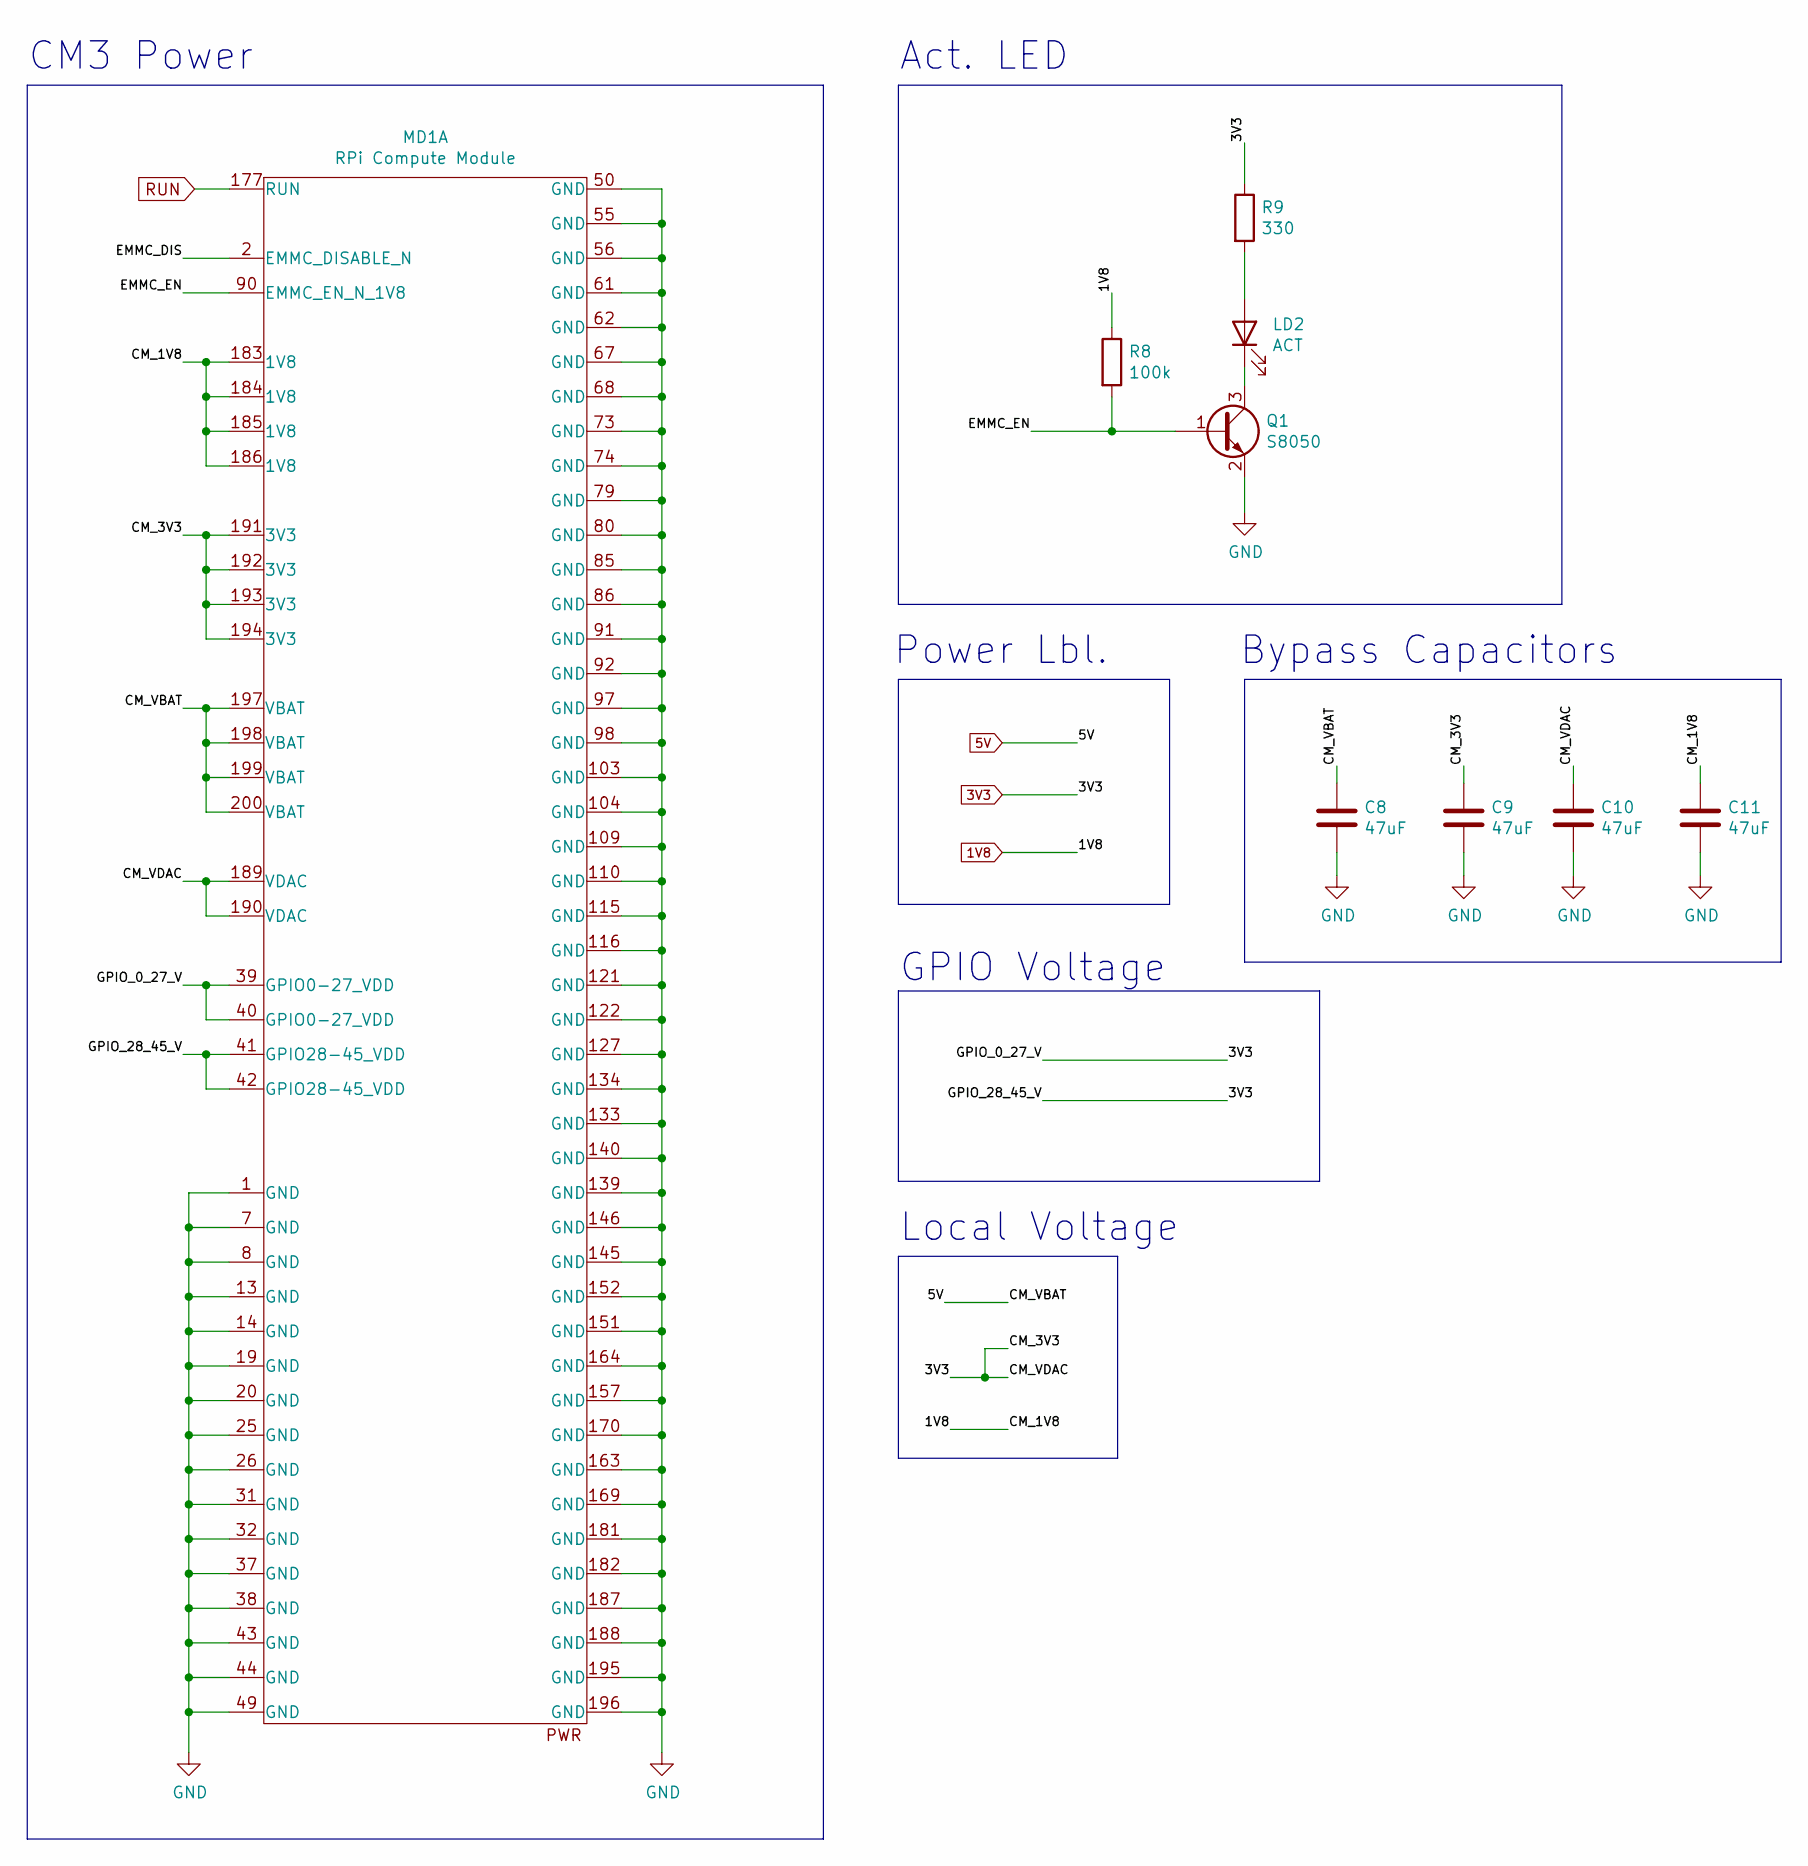
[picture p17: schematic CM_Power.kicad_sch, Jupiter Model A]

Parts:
C8, C9, C10, C11: 47uF; C_1206_3216Metric
LD2: ACT; LED_0805_2012Metric
MD1: RPi Compute Module; Conn_TE-DDR2-SODIMM-0.6-200P-doublesided
Q1: S8050; SOT-23
R8: 100k; R_0603_1608Metric
R9: 330; R_0603_1608Metric

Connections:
1V8: C11.1, MD1.183 (1V8), MD1.184 (1V8), MD1.185 (1V8), MD1.186 (1V8), R8.1; also elsewhere on the board
3V3: C9.1, C10.1, MD1.39 (GPIO0-27_VDD), MD1.40 (GPIO0-27_VDD), MD1.41 (GPIO28-45_VDD), MD1.42 (GPIO28-45_VDD), MD1.189 (VDAC), MD1.190 (VDAC), MD1.191 (3V3), MD1.192 (3V3), MD1.193 (3V3), MD1.194 (3V3), R9.1; also elsewhere on the board
5V: C8.1, MD1.197 (VBAT), MD1.198 (VBAT), MD1.199 (VBAT), MD1.200 (VBAT); also elsewhere on the board
/CM_Power/EMMC_DIS: MD1.2 (EMMC_DISABLE_N)
/CM_Power/EMMC_EN: MD1.90 (EMMC_EN_N_1V8), Q1.1 (B), R8.2
GND: C8.2, C9.2, C10.2, C11.2, MD1.1 (GND), MD1.7 (GND), MD1.8 (GND), MD1.13 (GND), MD1.14 (GND), MD1.19 (GND), MD1.20 (GND), MD1.25 (GND), MD1.26 (GND), MD1.31 (GND), MD1.32 (GND), MD1.37 (GND), MD1.38 (GND), MD1.43 (GND), MD1.44 (GND), MD1.49 (GND), MD1.50 (GND), MD1.55 (GND), MD1.56 (GND), MD1.61 (GND), MD1.62 (GND), MD1.67 (GND), MD1.68 (GND), MD1.73 (GND), MD1.74 (GND), MD1.79 (GND), MD1.80 (GND), MD1.85 (GND), MD1.86 (GND), MD1.91 (GND), MD1.92 (GND), MD1.97 (GND), MD1.98 (GND), MD1.103 (GND), MD1.104 (GND), MD1.109 (GND), MD1.110 (GND), MD1.115 (GND), MD1.116 (GND), MD1.121 (GND), MD1.122 (GND), MD1.127 (GND), MD1.133 (GND), MD1.134 (GND), MD1.139 (GND), MD1.140 (GND), MD1.145 (GND), MD1.146 (GND), MD1.151 (GND), MD1.152 (GND), MD1.157 (GND), MD1.163 (GND), MD1.164 (GND), MD1.169 (GND), MD1.170 (GND), MD1.181 (GND), MD1.182 (GND), MD1.187 (GND), MD1.188 (GND), MD1.195 (GND), MD1.196 (GND), Q1.2 (E); also elsewhere on the board
unnamed: LD2.1 (K), Q1.3 (C)
unnamed: LD2.2 (A), R9.2
RUN: MD1.177 (RUN); also elsewhere on the board

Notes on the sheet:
GPIO Voltage
Bypass Capacitors
Power Lbl.
CM3 Power
Act. LED
Local Voltage

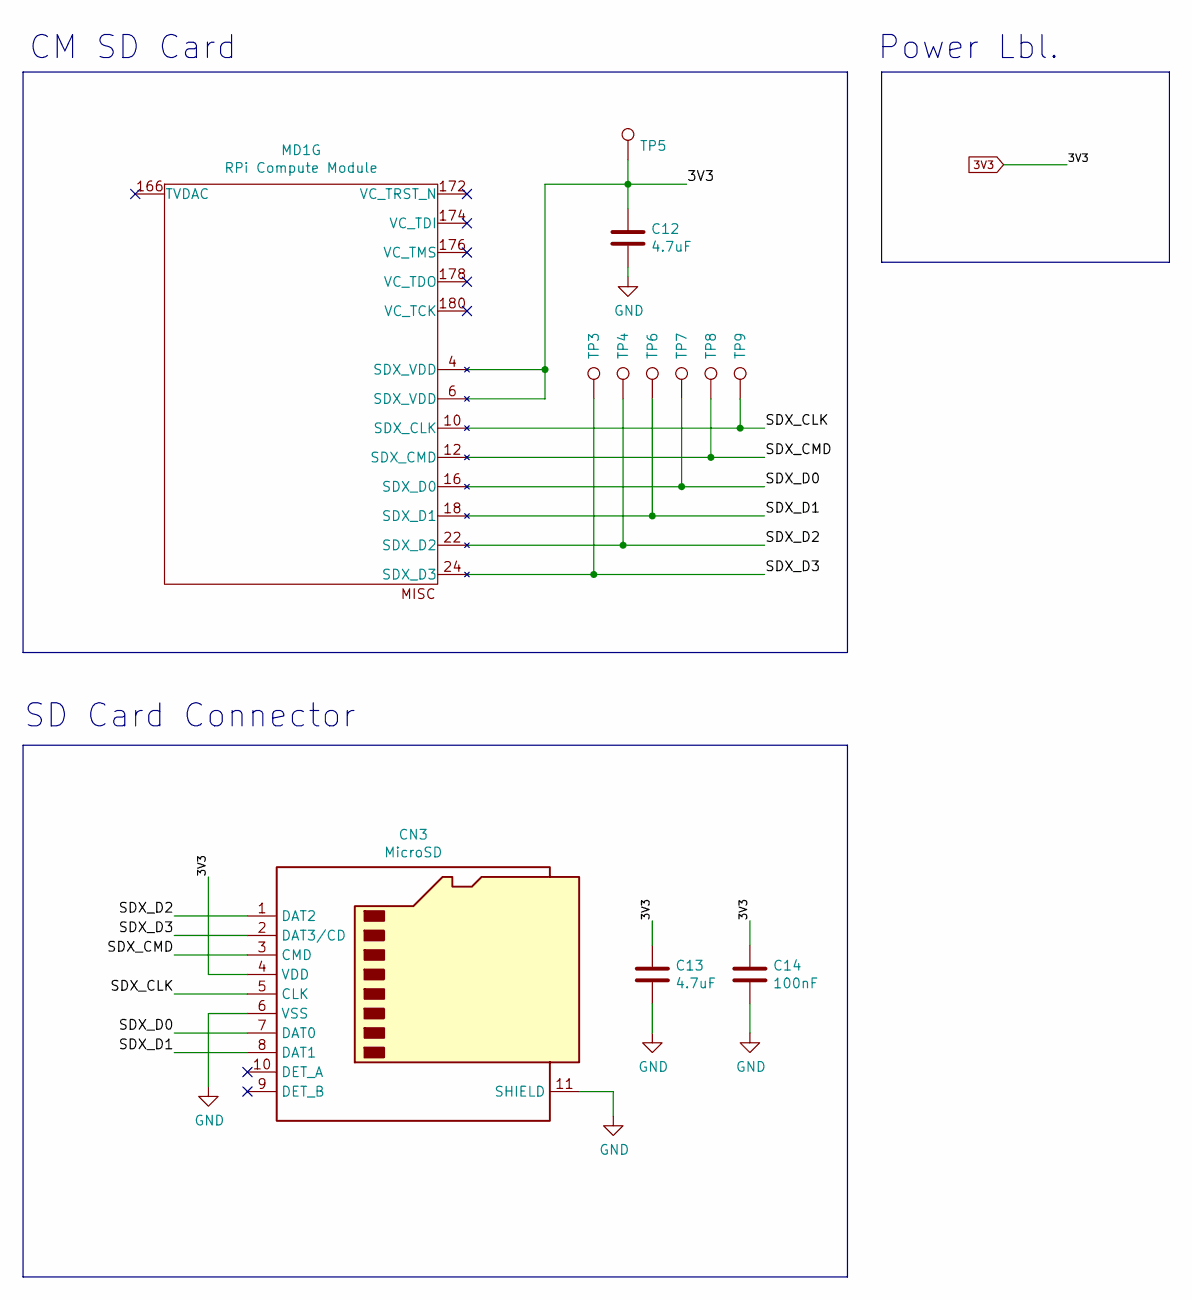
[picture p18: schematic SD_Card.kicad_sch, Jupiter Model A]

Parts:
C12, C13: 4.7uF; C_1206_3216Metric
C14: 100nF; C_0805_2012Metric
CN3: MicroSD; microSD_HC_Hirose_DM3D-SF
MD1: RPi Compute Module; Conn_TE-DDR2-SODIMM-0.6-200P-doublesided
TP3, TP4, TP5, TP6, TP7, TP8, TP9: TestPoint_Pad_D1.0mm

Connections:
3V3: C12.1, C13.1, C14.1, CN3.4 (VDD), MD1.4 (SDX_VDD), MD1.6 (SDX_VDD), TP5.1; also elsewhere on the board
/SD_Card/SDX_CLK: CN3.5 (CLK), MD1.10 (SDX_CLK), TP9.1
/SD_Card/SDX_CMD: CN3.3 (CMD), MD1.12 (SDX_CMD), TP8.1
/SD_Card/SDX_D0: CN3.7 (DAT0), MD1.16 (SDX_D0), TP7.1
/SD_Card/SDX_D1: CN3.8 (DAT1), MD1.18 (SDX_D1), TP6.1
/SD_Card/SDX_D2: CN3.1 (DAT2), MD1.22 (SDX_D2), TP4.1
/SD_Card/SDX_D3: CN3.2 (DAT3/CD), MD1.24 (SDX_D3), TP3.1
GND: C12.2, C13.2, C14.2, CN3.6 (VSS), CN3.11 (SHIELD); also elsewhere on the board

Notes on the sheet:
Power Lbl.
SD Card Connector
CM SD Card

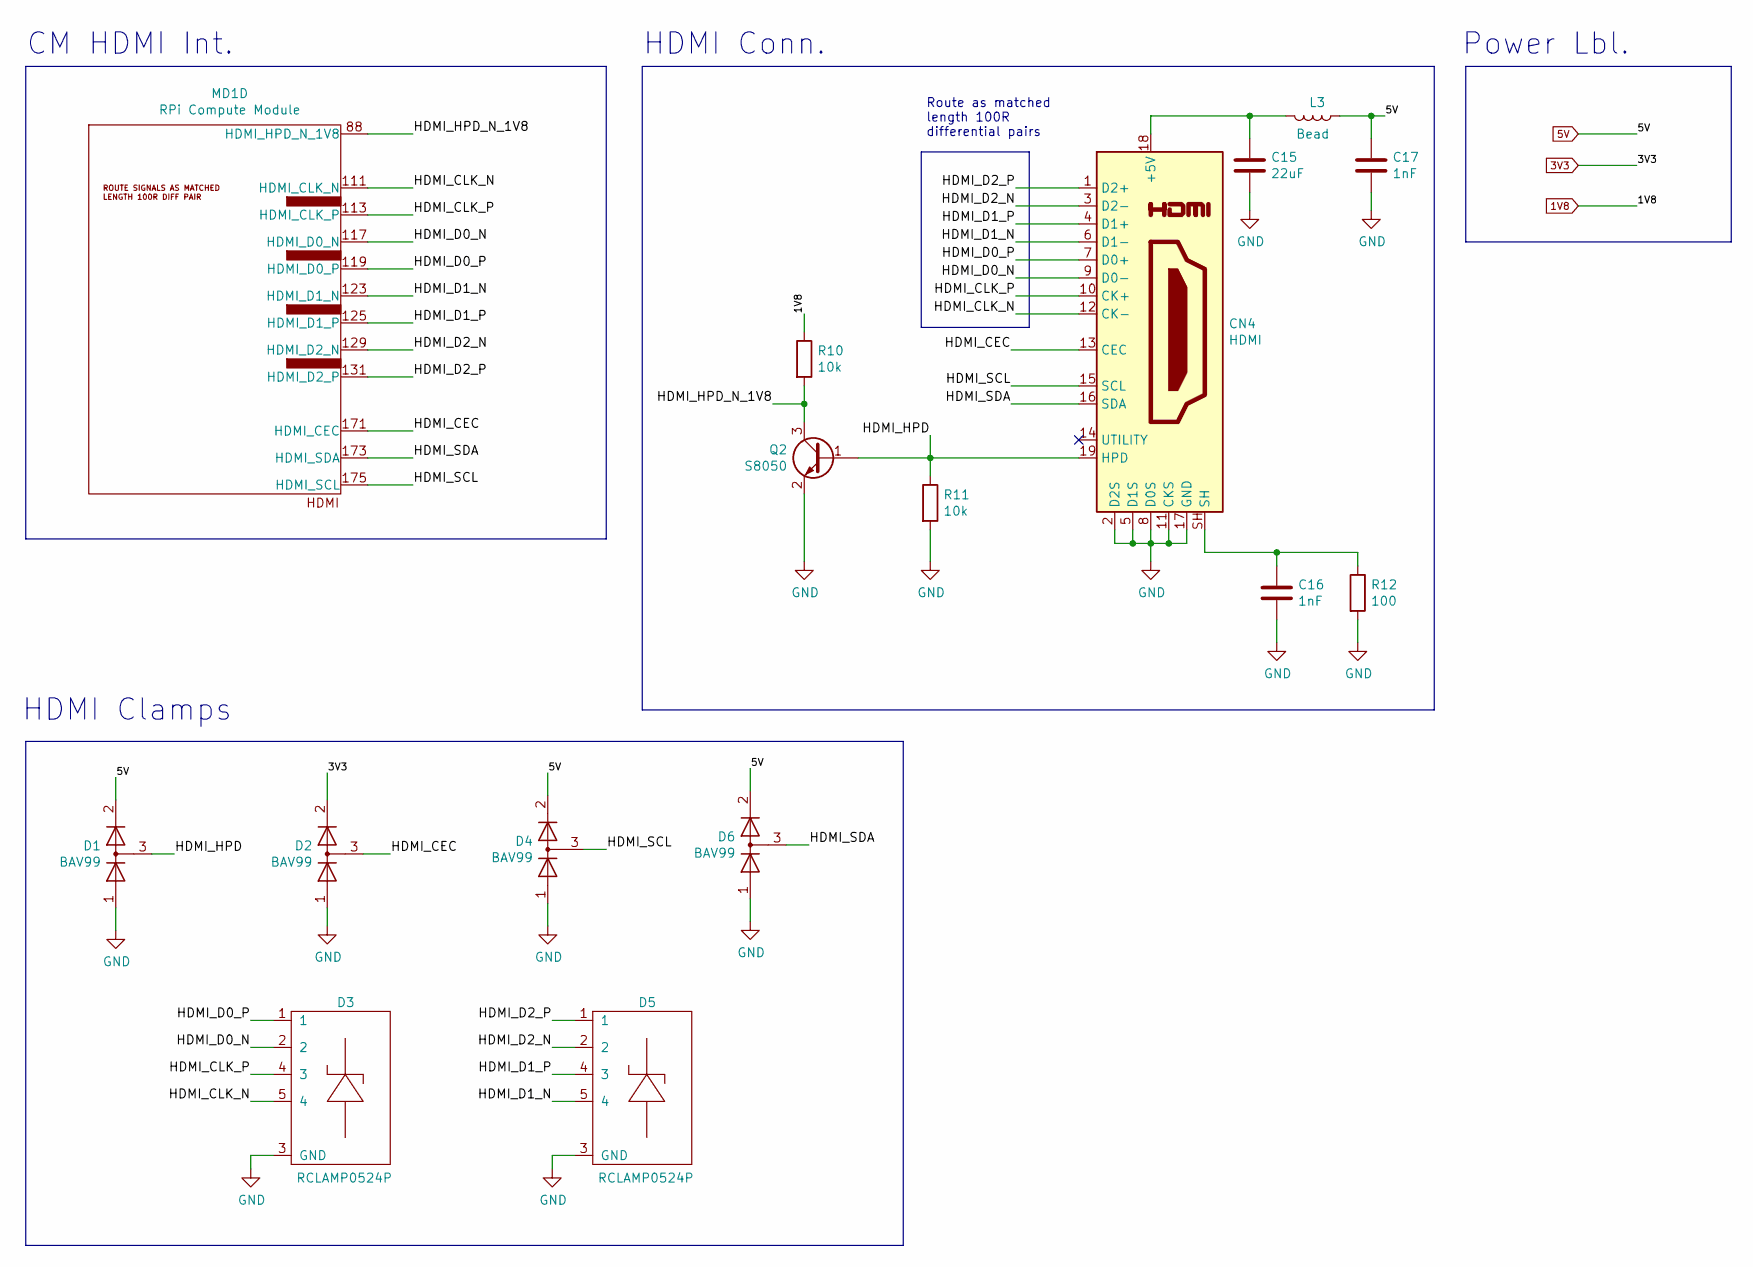
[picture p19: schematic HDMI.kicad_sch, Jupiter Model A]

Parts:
C15: 22uF; C_0805_2012Metric
C16: 1nF; C_0603_1608Metric
C17: 1nF; C_0805_2012Metric
CN4: HDMI; HDMI_TypeA
D1, D2, D4, D6: BAV99; SOT-23
D3, D5: RCLAMP0524P
L3: Bead; L_0805_2012Metric
MD1: RPi Compute Module; Conn_TE-DDR2-SODIMM-0.6-200P-doublesided
Q2: S8050; SOT-23
R10, R11: 10k; R_0603_1608Metric
R12: 100; R_0603_1608Metric

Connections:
1V8: R10.1; also elsewhere on the board
3V3: D2.2 (A); also elsewhere on the board
5V: C17.1, D1.2 (A), D4.2 (A), D6.2 (A), L3.1; also elsewhere on the board
/HDMI/HDMI_CEC: CN4.13 (CEC), D2.3 (K), MD1.171 (HDMI_CEC)
/HDMI/HDMI_CLK_N: CN4.12 (CK-), D3.5 (4), MD1.111 (HDMI_CLK_N)
/HDMI/HDMI_CLK_P: CN4.10 (CK+), D3.4 (3), MD1.113 (HDMI_CLK_P)
/HDMI/HDMI_D0_N: CN4.9 (D0-), D3.2, MD1.117 (HDMI_D0_N)
/HDMI/HDMI_D0_P: CN4.7 (D0+), D3.1, MD1.119 (HDMI_D0_P)
/HDMI/HDMI_D1_N: CN4.6 (D1-), D5.5 (4), MD1.123 (HDMI_D1_N)
/HDMI/HDMI_D1_P: CN4.4 (D1+), D5.4 (3), MD1.125 (HDMI_D1_P)
/HDMI/HDMI_D2_N: CN4.3 (D2-), D5.2, MD1.129 (HDMI_D2_N)
/HDMI/HDMI_D2_P: CN4.1 (D2+), D5.1, MD1.131 (HDMI_D2_P)
/HDMI/HDMI_HPD: CN4.19 (HPD), D1.3 (K), Q2.1 (B), R11.1
/HDMI/HDMI_HPD_N_1V8: MD1.88 (HDMI_HPD_N_1V8), Q2.3 (C), R10.2
/HDMI/HDMI_SCL: CN4.15 (SCL), D4.3 (K), MD1.175 (HDMI_SCL)
/HDMI/HDMI_SDA: CN4.16 (SDA), D6.3 (K), MD1.173 (HDMI_SDA)
GND: C15.2, C16.2, C17.2, CN4.2 (D2S), CN4.5 (D1S), CN4.8 (D0S), CN4.11 (CKS), CN4.17 (GND), D1.1 (K), D2.1 (K), D3.3 (GND), D4.1 (K), D5.3 (GND), D6.1 (K), Q2.2 (E), R11.2, R12.2; also elsewhere on the board
unnamed: C15.1, CN4.18 (+5V), L3.2
unnamed: C16.1, CN4.SH, R12.1

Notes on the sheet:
Power Lbl.
Route as matched length 100R differential pairs
HDMI Conn.
CM HDMI Int.
HDMI Clamps

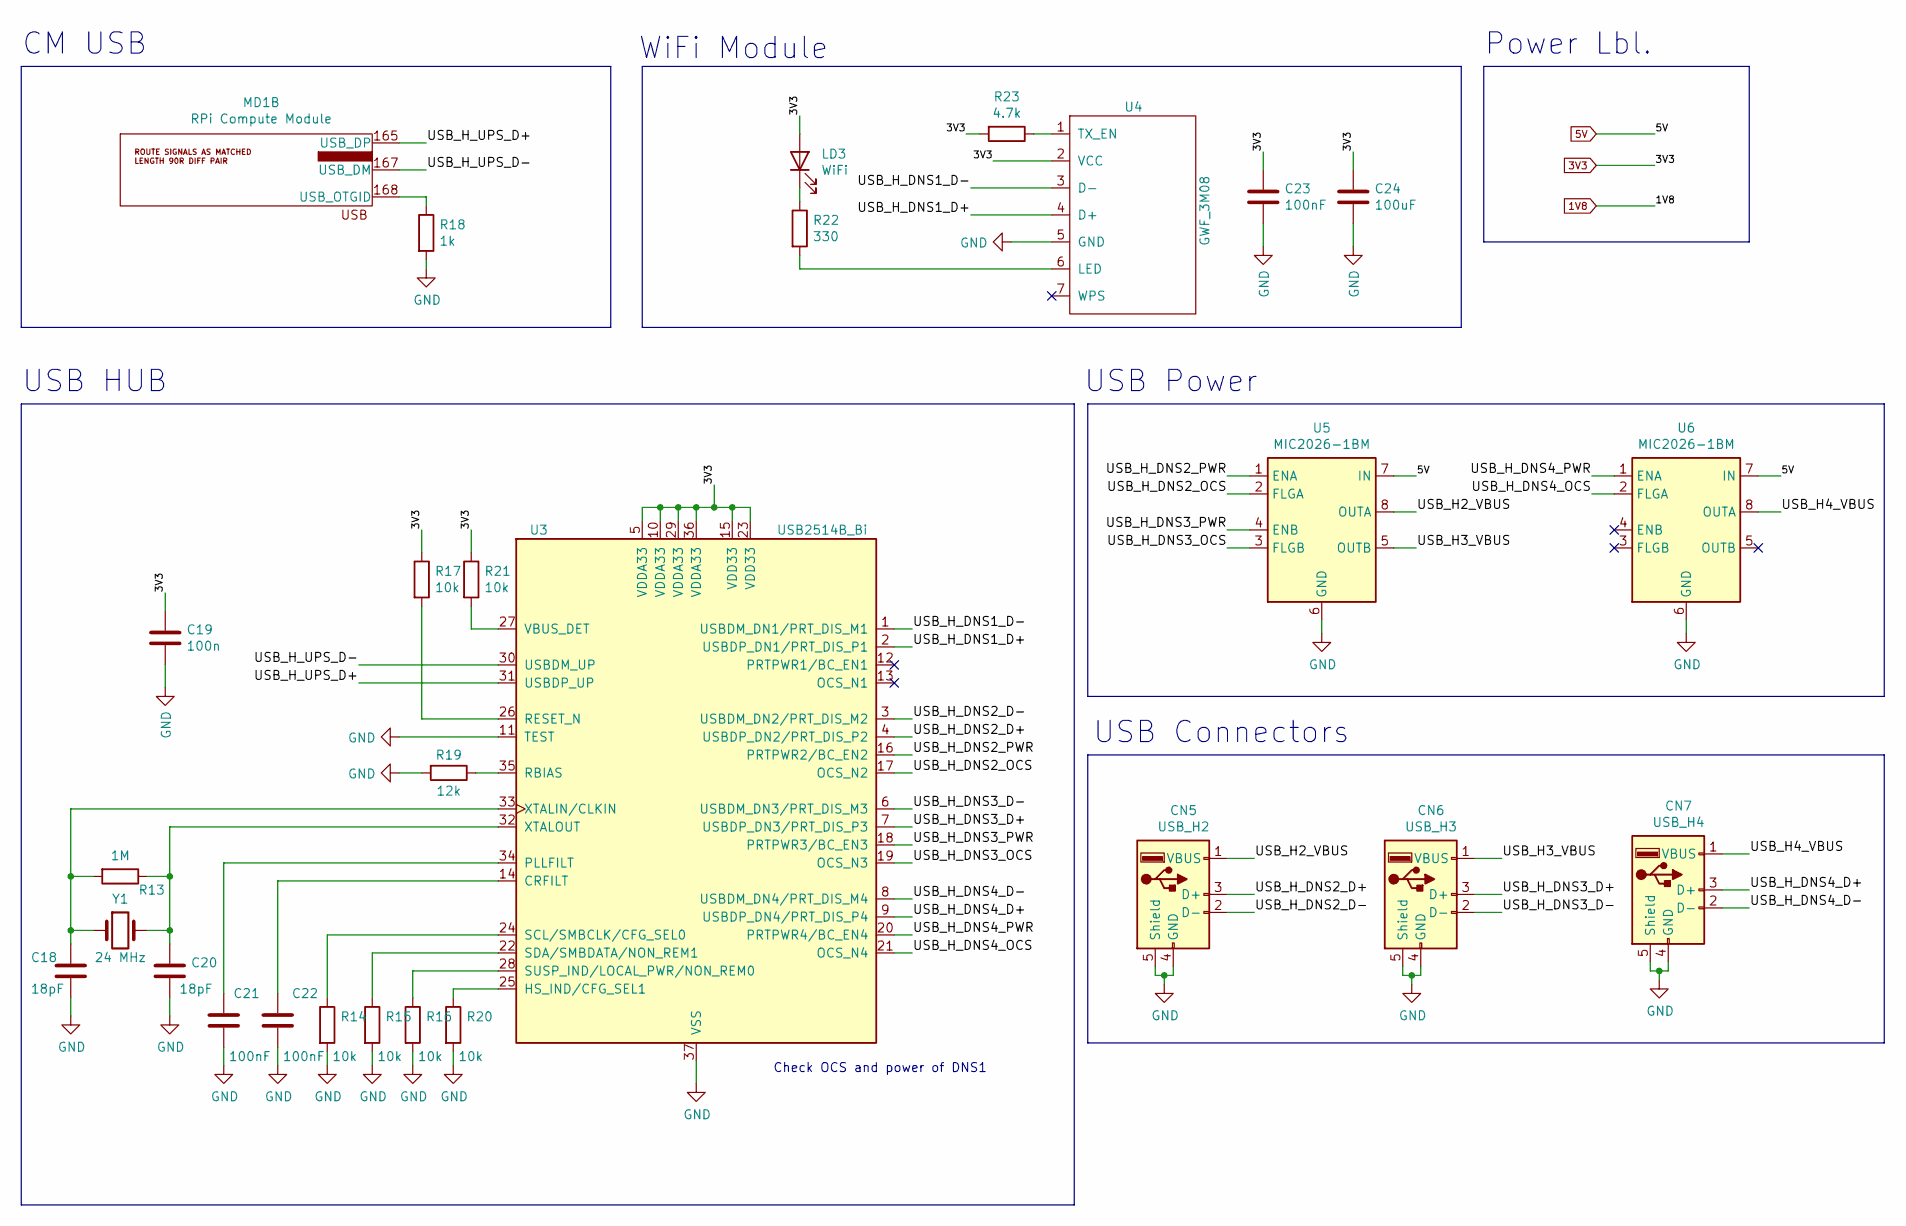
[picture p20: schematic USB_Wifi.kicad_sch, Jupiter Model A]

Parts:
C18, C20: 18pF; C_0603_1608Metric
C19: 100n; C_0805_2012Metric
C21, C22, C23: 100nF; C_0805_2012Metric
C24: 100uF; C_1206_3216Metric
CN5: USB_H2; USB_A_Stewart_SS-52100-001_Horizontal
CN6: USB_H3; USB_A_Stewart_SS-52100-001_Horizontal
CN7: USB_H4; USB_A_Stewart_SS-52100-001_Horizontal
LD3: WiFi; LED_0805_2012Metric
MD1: RPi Compute Module; Conn_TE-DDR2-SODIMM-0.6-200P-doublesided
R13: 1M; R_0603_1608Metric
R14, R15, R16, R17, R20, R21: 10k; R_0603_1608Metric
R18: 1k; R_0603_1608Metric
R19: 12k; R_0603_1608Metric
R22: 330; R_0603_1608Metric
R23: 4.7k; R_0603_1608Metric
U3: USB2514B_Bi; QFN-36-1EP_6x6mm_P0.5mm_EP3.7x3.7mm
U4: GWF_3M08; GWF_3M08_WifiModule
U5, U6: MIC2026-1BM; SOIC-8_3.9x4.9mm_P1.27mm
Y1: 24 MHz; Crystal_SMD_5032-2Pin_5.0x3.2mm

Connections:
3V3: C19.1, C23.1, C24.1, LD3.2 (A), R17.1, R21.1, R23.2, U3.5 (VDDA33), U3.10 (VDDA33), U3.15 (VDD33), U3.23 (VDD33), U3.29 (VDDA33), U3.36 (VDDA33), U4.2 (VCC); also elsewhere on the board
5V: U5.7 (IN), U6.7 (IN); also elsewhere on the board
/USB_Wifi/USB_H2_VBUS: CN5.1 (VBUS), U5.8 (OUTA)
/USB_Wifi/USB_H3_VBUS: CN6.1 (VBUS), U5.5 (OUTB)
/USB_Wifi/USB_H4_VBUS: CN7.1 (VBUS), U6.8 (OUTA)
/USB_Wifi/USB_H_DNS1_D+: U3.2 (USBDP_DN1/PRT_DIS_P1), U4.4 (D+)
/USB_Wifi/USB_H_DNS1_D-: U3.1 (USBDM_DN1/PRT_DIS_M1), U4.3 (D-)
/USB_Wifi/USB_H_DNS2_D+: CN5.3 (D+), U3.4 (USBDP_DN2/PRT_DIS_P2)
/USB_Wifi/USB_H_DNS2_D-: CN5.2 (D-), U3.3 (USBDM_DN2/PRT_DIS_M2)
/USB_Wifi/USB_H_DNS2_OCS: U3.17 (OCS_N2), U5.2 (FLGA)
/USB_Wifi/USB_H_DNS2_PWR: U3.16 (PRTPWR2/BC_EN2), U5.1 (ENA)
/USB_Wifi/USB_H_DNS3_D+: CN6.3 (D+), U3.7 (USBDP_DN3/PRT_DIS_P3)
/USB_Wifi/USB_H_DNS3_D-: CN6.2 (D-), U3.6 (USBDM_DN3/PRT_DIS_M3)
/USB_Wifi/USB_H_DNS3_OCS: U3.19 (OCS_N3), U5.3 (FLGB)
/USB_Wifi/USB_H_DNS3_PWR: U3.18 (PRTPWR3/BC_EN3), U5.4 (ENB)
/USB_Wifi/USB_H_DNS4_D+: CN7.3 (D+), U3.9 (USBDP_DN4/PRT_DIS_P4)
/USB_Wifi/USB_H_DNS4_D-: CN7.2 (D-), U3.8 (USBDM_DN4/PRT_DIS_M4)
/USB_Wifi/USB_H_DNS4_OCS: U3.21 (OCS_N4), U6.2 (FLGA)
/USB_Wifi/USB_H_DNS4_PWR: U3.20 (PRTPWR4/BC_EN4), U6.1 (ENA)
/USB_Wifi/USB_H_UPS_D+: MD1.165 (USB_DP), U3.31 (USBDP_UP)
/USB_Wifi/USB_H_UPS_D-: MD1.167 (USB_DM), U3.30 (USBDM_UP)
GND: C18.2, C19.2, C20.2, C21.2, C22.2, C23.2, C24.2, CN5.4 (GND), CN5.5 (Shield), CN6.4 (GND), CN6.5 (Shield), CN7.4 (GND), CN7.5 (Shield), R14.2, R15.2, R16.2, R18.2, R19.2, R20.2, U3.11 (TEST), U3.37 (VSS), U4.5 (GND), U5.6 (GND), U6.6 (GND); also elsewhere on the board
unnamed: C18.1, R13.2, U3.33 (XTALIN/CLKIN), Y1.1
unnamed: C20.1, R13.1, U3.32 (XTALOUT), Y1.2
unnamed: C21.1, U3.34 (PLLFILT)
unnamed: C22.1, U3.14 (CRFILT)
unnamed: LD3.1 (K), R22.1
unnamed: MD1.168 (USB_OTGID), R18.1
unnamed: R14.1, U3.24 (SCL/SMBCLK/CFG_SEL0)
unnamed: R15.1, U3.22 (SDA/SMBDATA/NON_REM1)
unnamed: R16.1, U3.28 (SUSP_IND/LOCAL_PWR/NON_REM0)
unnamed: R17.2, U3.26 (RESET_N)
unnamed: R19.1, U3.35 (RBIAS)
unnamed: R20.1, U3.25 (HS_IND/CFG_SEL1)
unnamed: R21.2, U3.27 (VBUS_DET)
unnamed: R22.2, U4.6 (LED)
unnamed: R23.1, U4.1 (TX_EN)

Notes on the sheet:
WiFi Module
USB Power
CM USB
Power Lbl.
USB HUB
Check OCS and power of DNS1
USB Connectors

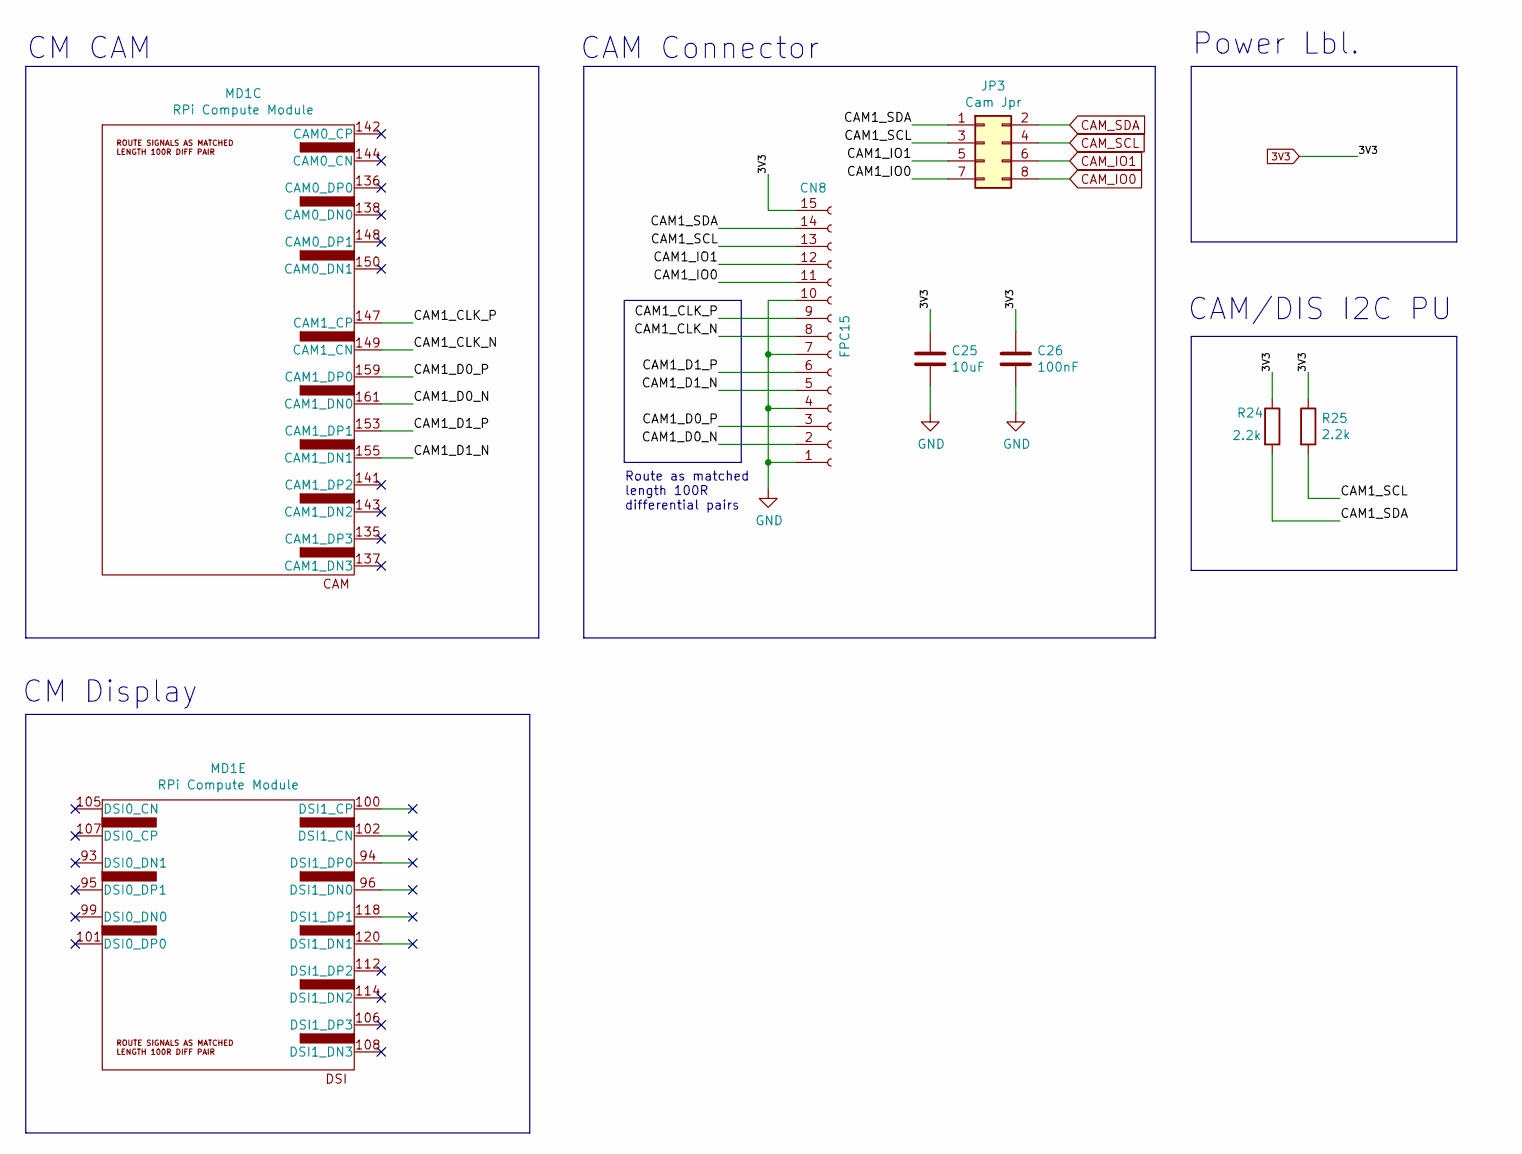
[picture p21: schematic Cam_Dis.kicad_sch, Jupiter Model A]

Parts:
C25: 10uF; C_1206_3216Metric
C26: 100nF; C_0805_2012Metric
CN8: FPC15; TE_1-84952-5_1x15-1MP_P1.0mm_Horizontal
JP3: Cam Jpr; PinHeader_2x04_P2.54mm_Vertical
MD1: RPi Compute Module; Conn_TE-DDR2-SODIMM-0.6-200P-doublesided
R24, R25: 2.2k; R_0603_1608Metric

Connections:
3V3: C25.1, C26.1, CN8.15, R24.1, R25.1; also elsewhere on the board
/Cam_Dis/CAM1_CLK_N: CN8.8, MD1.149 (CAM1_CN)
/Cam_Dis/CAM1_CLK_P: CN8.9, MD1.147 (CAM1_CP)
/Cam_Dis/CAM1_D0_N: CN8.2, MD1.161 (CAM1_DN0)
/Cam_Dis/CAM1_D0_P: CN8.3, MD1.159 (CAM1_DP0)
/Cam_Dis/CAM1_D1_N: CN8.5, MD1.155 (CAM1_DN1)
/Cam_Dis/CAM1_D1_P: CN8.6, MD1.153 (CAM1_DP1)
/Cam_Dis/CAM1_IO0: CN8.11, JP3.7
/Cam_Dis/CAM1_IO1: CN8.12, JP3.5
/Cam_Dis/CAM1_SCL: CN8.13, JP3.3, R25.2
/Cam_Dis/CAM1_SDA: CN8.14, JP3.1, R24.2
CAM_IO0: JP3.8; also elsewhere on the board
CAM_IO1: JP3.6; also elsewhere on the board
CAM_SCL: JP3.4; also elsewhere on the board
CAM_SDA: JP3.2; also elsewhere on the board
GND: C25.2, C26.2, CN8.1, CN8.4, CN8.7, CN8.10; also elsewhere on the board

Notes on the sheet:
CAM/DIS I2C PU
CAM Connector
CM Display
CM CAM
Power Lbl.
Route as matched length 100R differential pairs

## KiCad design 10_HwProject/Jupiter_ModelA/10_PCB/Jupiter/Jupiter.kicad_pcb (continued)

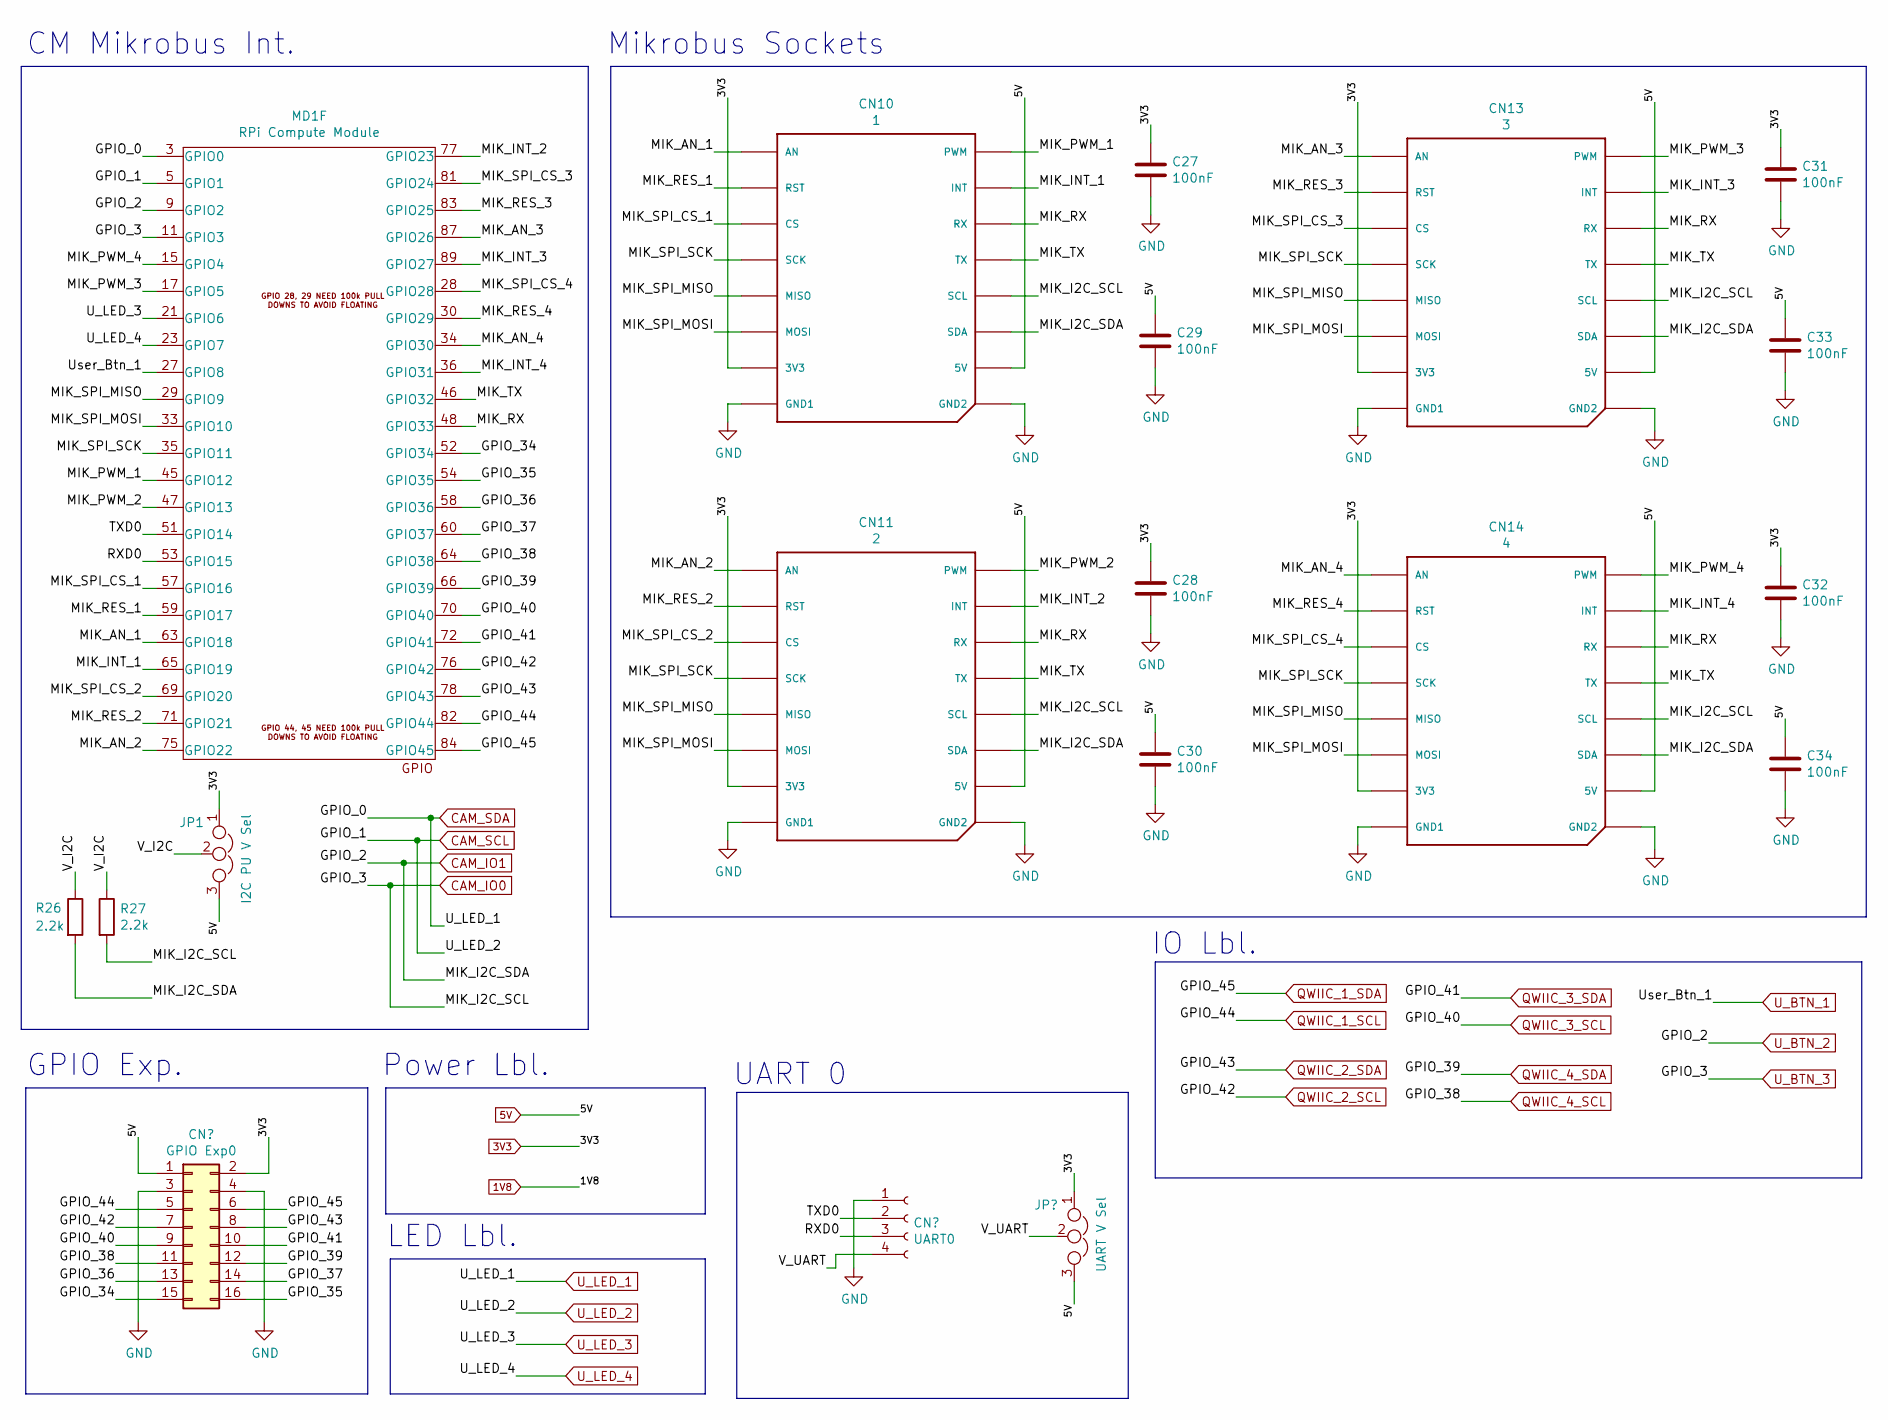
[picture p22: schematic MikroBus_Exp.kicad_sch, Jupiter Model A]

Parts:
C27, C28, C29, C30, C31, C32, C33, C34: 100nF; C_0805_2012Metric
CN9: GPIO Exp0; PinHeader_2x08_P2.54mm_Vertical
CN10: 1; MIKROBUS_HOST_CONN
CN11: 2; MIKROBUS_HOST_CONN
CN12: UART0; PinHeader_1x04_P2.54mm_Vertical
CN13: 3; MIKROBUS_HOST_CONN
CN14: 4; MIKROBUS_HOST_CONN
JP1: I2C PU V Sel; PinHeader_1x03_P2.54mm_Vertical
JP2: UART V Sel; PinHeader_1x03_P2.54mm_Vertical
MD1: RPi Compute Module; Conn_TE-DDR2-SODIMM-0.6-200P-doublesided
R26, R27: 2.2k; R_0603_1608Metric

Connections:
3V3: C27.1, C28.1, C31.1, C32.1, CN9.2, CN10.P7 (3V3), CN11.P7 (3V3), CN13.P7 (3V3), CN14.P7 (3V3), JP1.1, JP2.1; also elsewhere on the board
5V: C29.1, C30.1, C33.1, C34.1, CN9.1, CN10.P10 (5V), CN11.P10 (5V), CN13.P10 (5V), CN14.P10 (5V), JP1.3, JP2.3; also elsewhere on the board
/MikroBus_Exp/GPIO_34: CN9.15, MD1.52 (GPIO34)
/MikroBus_Exp/GPIO_35: CN9.16, MD1.54 (GPIO35)
/MikroBus_Exp/GPIO_36: CN9.13, MD1.58 (GPIO36)
/MikroBus_Exp/GPIO_37: CN9.14, MD1.60 (GPIO37)
/MikroBus_Exp/MIK_AN_1: CN10.P1 (AN), MD1.63 (GPIO18)
/MikroBus_Exp/MIK_AN_2: CN11.P1 (AN), MD1.75 (GPIO22)
/MikroBus_Exp/MIK_AN_3: CN13.P1 (AN), MD1.87 (GPIO26)
/MikroBus_Exp/MIK_AN_4: CN14.P1 (AN), MD1.34 (GPIO30)
/MikroBus_Exp/MIK_INT_1: CN10.P15 (INT), MD1.65 (GPIO19)
/MikroBus_Exp/MIK_INT_2: CN11.P15 (INT), MD1.77 (GPIO23)
/MikroBus_Exp/MIK_INT_3: CN13.P15 (INT), MD1.89 (GPIO27)
/MikroBus_Exp/MIK_INT_4: CN14.P15 (INT), MD1.36 (GPIO31)
/MikroBus_Exp/MIK_PWM_1: CN10.P16 (PWM), MD1.45 (GPIO12)
/MikroBus_Exp/MIK_PWM_2: CN11.P16 (PWM), MD1.47 (GPIO13)
/MikroBus_Exp/MIK_PWM_3: CN13.P16 (PWM), MD1.17 (GPIO5)
/MikroBus_Exp/MIK_PWM_4: CN14.P16 (PWM), MD1.15 (GPIO4)
/MikroBus_Exp/MIK_RES_1: CN10.P2 (RST), MD1.59 (GPIO17)
/MikroBus_Exp/MIK_RES_2: CN11.P2 (RST), MD1.71 (GPIO21)
/MikroBus_Exp/MIK_RES_3: CN13.P2 (RST), MD1.83 (GPIO25)
/MikroBus_Exp/MIK_RES_4: CN14.P2 (RST), MD1.30 (GPIO29)
/MikroBus_Exp/MIK_RX: CN10.P14 (RX), CN11.P14 (RX), CN13.P14 (RX), CN14.P14 (RX), MD1.48 (GPIO33)
/MikroBus_Exp/MIK_SPI_CS_1: CN10.P3 (CS), MD1.57 (GPIO16)
/MikroBus_Exp/MIK_SPI_CS_2: CN11.P3 (CS), MD1.69 (GPIO20)
/MikroBus_Exp/MIK_SPI_CS_3: CN13.P3 (CS), MD1.81 (GPIO24)
/MikroBus_Exp/MIK_SPI_CS_4: CN14.P3 (CS), MD1.28 (GPIO28)
/MikroBus_Exp/MIK_SPI_MISO: CN10.P5 (MISO), CN11.P5 (MISO), CN13.P5 (MISO), CN14.P5 (MISO), MD1.29 (GPIO9)
/MikroBus_Exp/MIK_SPI_MOSI: CN10.P6 (MOSI), CN11.P6 (MOSI), CN13.P6 (MOSI), CN14.P6 (MOSI), MD1.33 (GPIO10)
/MikroBus_Exp/MIK_SPI_SCK: CN10.P4 (SCK), CN11.P4 (SCK), CN13.P4 (SCK), CN14.P4 (SCK), MD1.35 (GPIO11)
/MikroBus_Exp/MIK_TX: CN10.P13 (TX), CN11.P13 (TX), CN13.P13 (TX), CN14.P13 (TX), MD1.46 (GPIO32)
/MikroBus_Exp/RXD0: CN12.3, MD1.53 (GPIO15)
/MikroBus_Exp/TXD0: CN12.2, MD1.51 (GPIO14)
/MikroBus_Exp/V_I2C: JP1.2, R26.1, R27.1
/MikroBus_Exp/V_UART: CN12.4, JP2.2
CAM_IO0: CN10.P12 (SCL), CN11.P12 (SCL), CN13.P12 (SCL), CN14.P12 (SCL), MD1.11 (GPIO3), R27.2; also elsewhere on the board
CAM_IO1: CN10.P11 (SDA), CN11.P11 (SDA), CN13.P11 (SDA), CN14.P11 (SDA), MD1.9 (GPIO2), R26.2; also elsewhere on the board
CAM_SCL: MD1.5 (GPIO1); also elsewhere on the board
CAM_SDA: MD1.3 (GPIO0); also elsewhere on the board
GND: C27.2, C28.2, C29.2, C30.2, C31.2, C32.2, C33.2, C34.2, CN9.3, CN9.4, CN10.P8 (GND1), CN10.P9 (GND2), CN11.P8 (GND1), CN11.P9 (GND2), CN12.1, CN13.P8 (GND1), CN13.P9 (GND2), CN14.P8 (GND1), CN14.P9 (GND2); also elsewhere on the board
QWIIC_1_SCL: CN9.5, MD1.82 (GPIO44); also elsewhere on the board
QWIIC_1_SDA: CN9.6, MD1.84 (GPIO45); also elsewhere on the board
QWIIC_2_SCL: CN9.7, MD1.76 (GPIO42); also elsewhere on the board
QWIIC_2_SDA: CN9.8, MD1.78 (GPIO43); also elsewhere on the board
QWIIC_3_SCL: CN9.9, MD1.70 (GPIO40); also elsewhere on the board
QWIIC_3_SDA: CN9.10, MD1.72 (GPIO41); also elsewhere on the board
QWIIC_4_SCL: CN9.11, MD1.64 (GPIO38); also elsewhere on the board
QWIIC_4_SDA: CN9.12, MD1.66 (GPIO39); also elsewhere on the board
U_BTN_1: MD1.27 (GPIO8); also elsewhere on the board
U_LED_3: MD1.21 (GPIO6); also elsewhere on the board
U_LED_4: MD1.23 (GPIO7); also elsewhere on the board

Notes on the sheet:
GPIO Exp.
IO Lbl.
CM Mikrobus Int.
UART 0
Mikrobus Sockets
Power Lbl.
LED Lbl.

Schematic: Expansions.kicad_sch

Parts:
CN15: QWIIC#1; JST_SH_SM04B-SRSS-TB_1x04-1MP_P1.00mm_Horizontal
CN16: QWIIC#2; JST_SH_SM04B-SRSS-TB_1x04-1MP_P1.00mm_Horizontal
CN17: GROVE#1; JST_PH_S4B-PH-SM4-TB_1x04-1MP_P2.00mm_Horizontal
CN18: GROVE#2; JST_PH_S4B-PH-SM4-TB_1x04-1MP_P2.00mm_Horizontal
LD4: U_LED_1; LED_0805_2012Metric
LD5: U_LED_2; LED_0805_2012Metric
LD6: U_LED_3; LED_0805_2012Metric
LD7: U_LED_4; LED_0805_2012Metric
R28, R29, R30, R31: 220; R_0603_1608Metric
R32, R33, R34, R35, R36, R37, R38, R39: 2.2k; R_0603_1608Metric
SW1: Reset; SW_SPST_B3U-1000P
SW2: User1; SW_SPST_B3U-1000P
SW3: User2; SW_SPST_B3U-1000P
SW4: User3; SW_SPST_B3U-1000P

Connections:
3V3: CN15.2, CN16.2, CN17.2, CN18.2, R32.1, R33.1, R34.1, R35.1, R36.1, R37.1, R38.1, R39.1; also elsewhere on the board
CAM_IO0: SW4.1; also elsewhere on the board
CAM_IO1: SW3.1; also elsewhere on the board
CAM_SCL: LD5.2 (A); also elsewhere on the board
CAM_SDA: LD4.2 (A); also elsewhere on the board
GND: CN15.1, CN16.1, CN17.1, CN18.1, R28.2, R29.2, R30.2, R31.2, SW1.2, SW2.2, SW3.2, SW4.2; also elsewhere on the board
unnamed: LD4.1 (K), R28.1
unnamed: LD5.1 (K), R29.1
unnamed: LD6.1 (K), R30.1
unnamed: LD7.1 (K), R31.1
QWIIC_1_SCL: CN15.4, R33.2; also elsewhere on the board
QWIIC_1_SDA: CN15.3, R32.2; also elsewhere on the board
QWIIC_2_SCL: CN16.4, R35.2; also elsewhere on the board
QWIIC_2_SDA: CN16.3, R34.2; also elsewhere on the board
QWIIC_3_SCL: CN17.4, R37.2; also elsewhere on the board
QWIIC_3_SDA: CN17.3, R36.2; also elsewhere on the board
QWIIC_4_SCL: CN18.4, R39.2; also elsewhere on the board
QWIIC_4_SDA: CN18.3, R38.2; also elsewhere on the board
RUN: SW1.1; also elsewhere on the board
U_BTN_1: SW2.1; also elsewhere on the board
U_LED_3: LD6.2 (A); also elsewhere on the board
U_LED_4: LD7.2 (A); also elsewhere on the board

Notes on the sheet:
GROVE Exp.
Power Lbl.
LEDs
QWIIC Exp.
Buttons

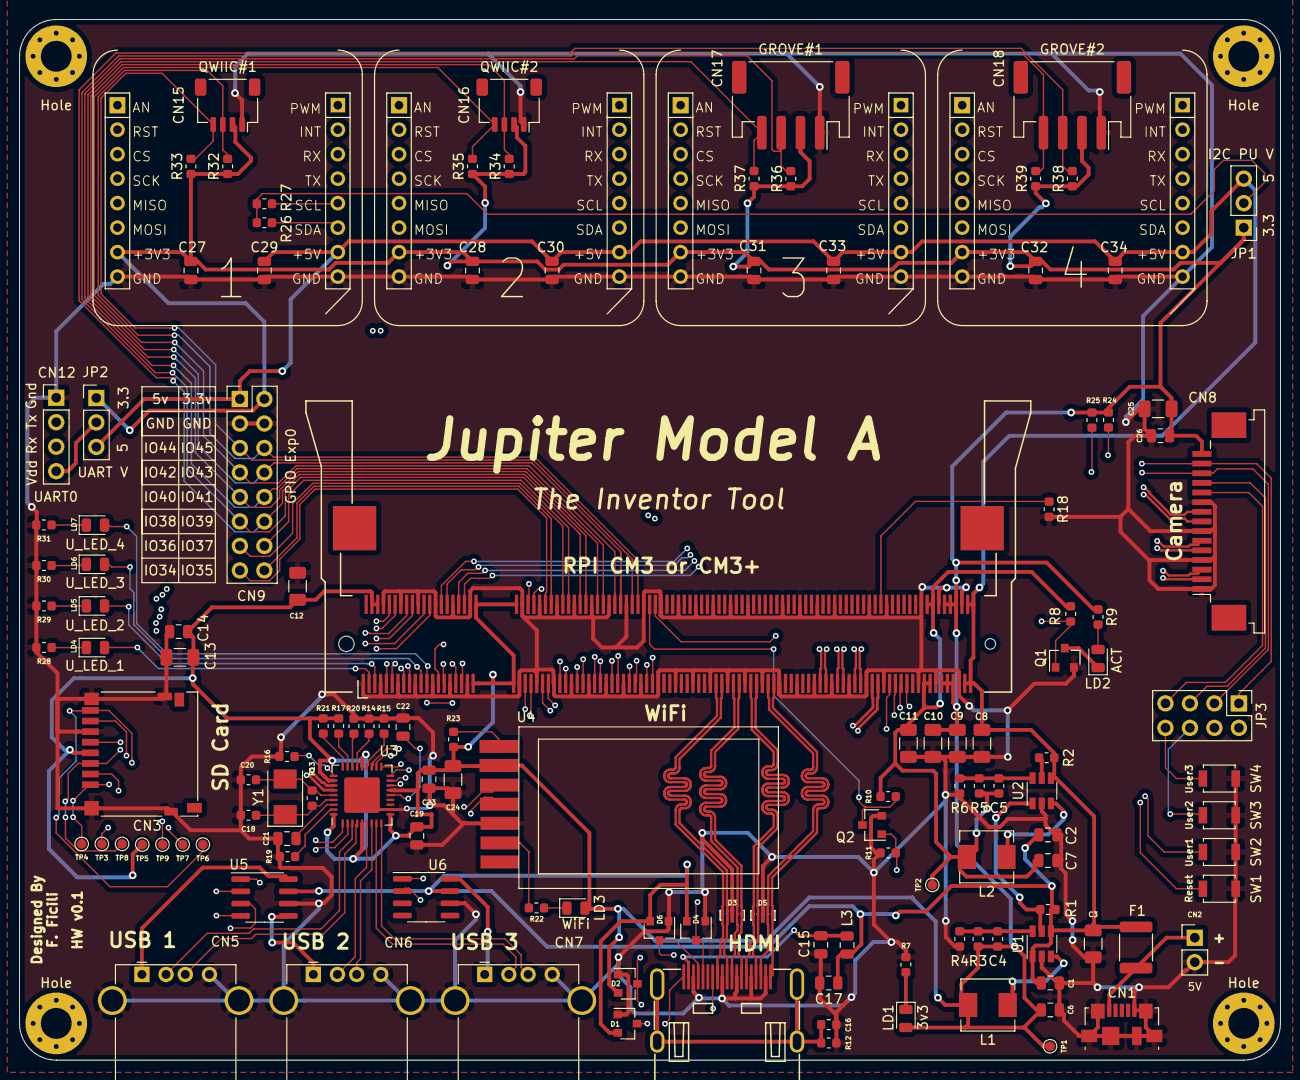
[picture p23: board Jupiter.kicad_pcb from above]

Board: 4 copper layers, 130.8 x 108.0 mm, 138 parts (0 on the bottom side), 133 nets.

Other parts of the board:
Hole: MountingHole_3.2mm_M3_Pad_Via
Hole#2, Hole#3, Hole#4: MountingHole_3.2mm_M3_Pad_Via

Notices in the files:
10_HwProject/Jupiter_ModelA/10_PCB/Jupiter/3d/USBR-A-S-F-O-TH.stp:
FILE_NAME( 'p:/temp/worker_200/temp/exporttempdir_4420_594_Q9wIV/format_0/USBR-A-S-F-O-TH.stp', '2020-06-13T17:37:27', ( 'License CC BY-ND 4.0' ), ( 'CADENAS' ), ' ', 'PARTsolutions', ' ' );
